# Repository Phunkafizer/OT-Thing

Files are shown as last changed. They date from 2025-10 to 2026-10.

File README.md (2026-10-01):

# OTthing

**A compact WiFi <-> OpenTherm (master & slave) interface**

## Project homepage

https://www.seegel-systeme.de/2025/01/05/ot-thing-das-universelle-wifi-opentherm-interface/

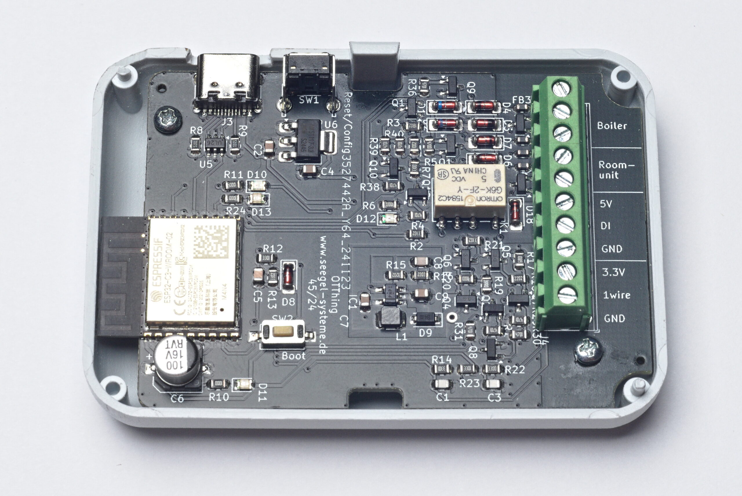
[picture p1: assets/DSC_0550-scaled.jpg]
OTthing OTthing board

*OTthing board*

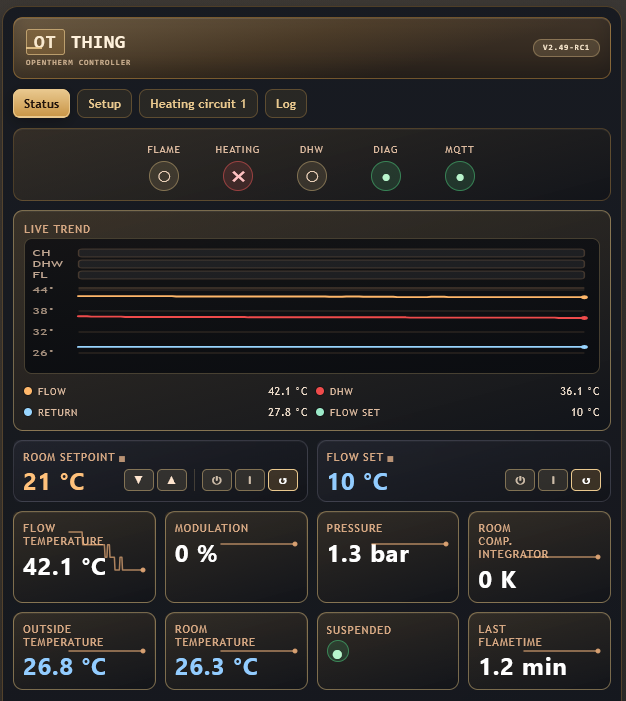
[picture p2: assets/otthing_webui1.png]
OTthing web UI OTthing web UI status

*OTthing web interface*

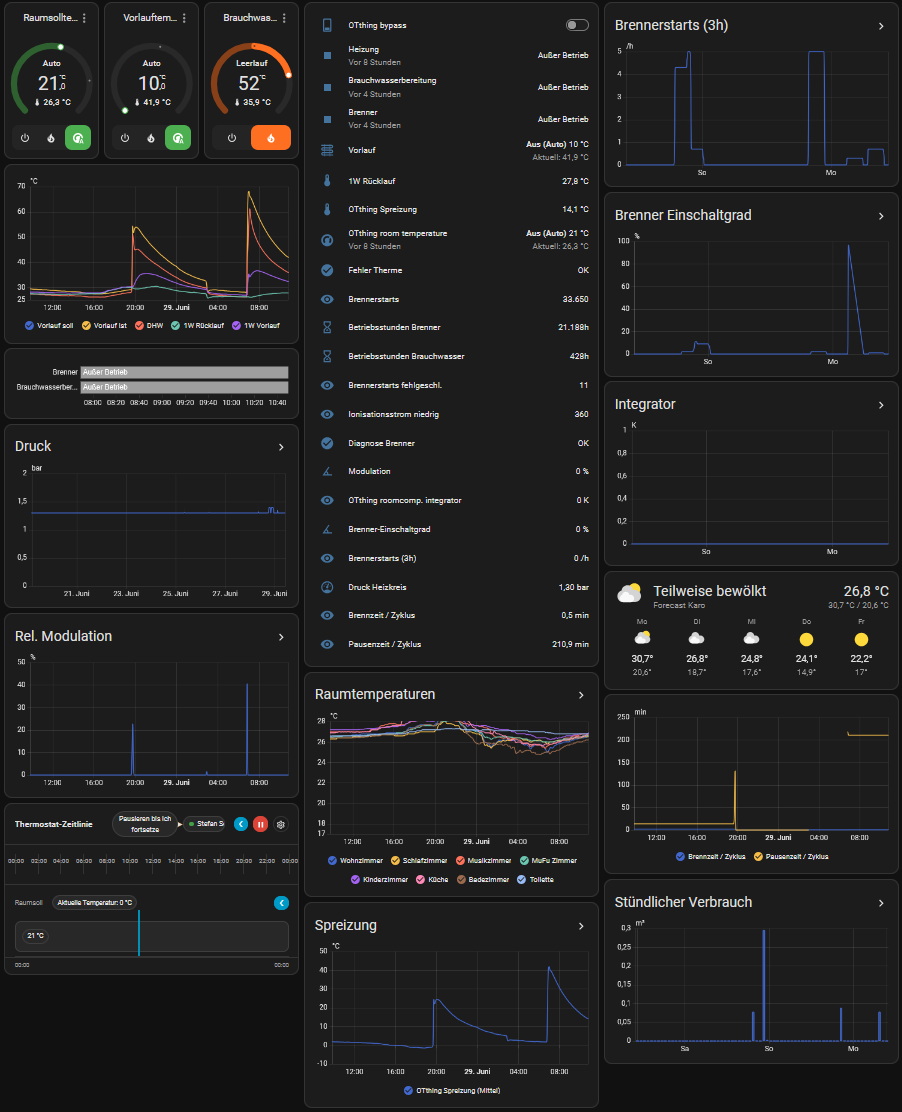
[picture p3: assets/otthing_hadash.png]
OTthing Home Assistant Dashboard OTthing Home Assistant dashboard

*Home Assistant integration*

## Overview

OTthing is a versatile OpenTherm gateway that connects your heating system to the Internet via WiFi. It acts as an OpenTherm master (controlling your boiler) and/or slave (integrating with room thermostats), providing real-time monitoring and control through a modern web interface and Home Assistant integration.

### Key Features

* **Dual OpenTherm Modes**: Operate as both an OpenTherm master and a slave simultaneously
* **Single-Board Compact Design**: Cost-efficient SMD-based single-board hardware with a small enclosure footprint
* **OpenTherm Compatibility**: Works with OpenTherm-compatible equipment that implements the functions supported by OTthing; available features vary by device
* **USB-C Powered**: Simple and reliable power supply through a standard USB-C connector
* **Web Dashboard**: Real-time status monitoring with system metrics
* **Home Assistant Integration**: Native MQTT discovery and seamless HA integration
* **Multi-Zone Support**: Control up to 2 heating circuits with independent parameters
* **Time Program**: Built-in scheduling for automatic heating setpoint changes
* **Heating Curve Control**: Outdoor-compensated flow temperature control with configurable curve parameters
* **Flow & Setpoint Management**: Fine-grained control for CH temperature targets, modes, and operating limits
* **Raw OpenTherm Tools**: Direct read/write request endpoint for diagnostics and advanced integrations
* **Real-Time Telemetry**: Live updates via WebSocket for logs and status changes
* **REST API**: Full HTTP interface for status, configuration, control commands, and topic discovery
* **WiFi Provisioning**: Built-in network scan and credential setup through the web interface
* **OTA Firmware Update**: In-browser firmware upload endpoint with automatic reboot on success
* **Local Data Export**: Device data and diagnostics export from the web UI for troubleshooting
* **External Inputs & Sensors**: Optional DS18B20, pulse input, or photointerrupter support (for example, condensate monitoring)
* **Selectable Operating Strategies**: Run OTthing as a full heating controller or in monitoring-first mode for telemetry-only operation
* **Automatic Bypass Behavior**: Allows you to restore conventional room-thermostat operation without rewiring
* **Failsafe Runtime Status**: Device health and communication state tracking for robust operation
* **Local Control**: Responsive web UI with no cloud dependency
* **Modular Design**: Extensible architecture supporting multiple integrations
* **Open-Source Platform**: Open hardware and firmware for custom extensions and modifications
* **Advanced Configuration**: Room modes (off/heat/auto), flow control, heating curves, and more
* **Detailed Logging**: Real-time log streaming to monitor system behavior
* **Turbo Mode**: Temporarily raises the flow target by a configurable amount and duration
* **Automatic Suspend**: Optional suspension based on outside temperature, room conditions, and minimum flow thresholds
* **Customizable dashboard**: add metrics to dashboard

## Architecture

The firmware consists of several functional modules:

* **OpenTherm Control** (`otcontrol.cpp`): Manages master/slave communication with the boiler
* **Master Requests** (`masterrequests.cpp`): Builds and schedules OpenTherm master requests and polling cycles
* **OpenTherm Values** (`otvalues.cpp`): Stores, normalizes, and exposes decoded OpenTherm data points
* **Heating Curve** (`heatingcurve.cpp`): Calculates the target flow temperature from heating-curve parameters
* **MQTT Integration** (`mqtt.cpp`): Publishes device state and subscribes to control topics
* **Device Status** (`devstatus.cpp`): Tracks runtime health, connectivity, and status flags
* **Auxiliary Input** (`auxInput.cpp`): Handles external input signals for additional control logic
* **Web Portal** (`portal.cpp`): Serves the responsive dashboard and API endpoints
* **Heating Control** (`CHcontrol.cpp`): Manages heating circuits, setpoints, and modes
* **Sensor Integration** (`sensors.cpp`): Collects data from external sensors
* **Configuration Management** (`devconfig.cpp`): Handles persistent device settings

## Hardware

* **MCU**: ESP32-C3 (or a compatible MCU with UART pins)
* **Communication**: OpenTherm interface
* **Power**: via USB
* **Optional**: DS18B20 1-Wire temperature sensors and auxiliary inputs

OpenTherm support and available controls depend on the boiler or other equipment. Check the device documentation and OTthing schematics before installation. Disconnect equipment from mains power before wiring; have boiler wiring performed by a qualified installer where required. Connect OpenTherm through the board's designated terminals, never directly to MCU GPIO pins.

## Installation & Setup

1. **Hardware Setup**:

   - Connect the OpenTherm slave side (boiler / ventilation / solar storage) to the **Boiler** screw terminal on OTthing
   - Optionally connect the room unit to the **Roomunit** screw terminals on OTthing
   - Connect OTthing to a USB-C power supply

2. **Access the Web Interface**:

   - The device creates a WiFi access point for provisioning or connects to its configured network
   - The default access point password is `12345678`; change it before deployment
   - Access the web UI at `http://<otthing-ip>/` (default: 4.3.2.1)

3. **Configure**:

   - Set your boiler type and heating circuit parameters
   - Configure the MQTT broker if you are using Home Assistant
   - Adjust setpoints, heating curves, and control modes

### Build and Flash (Developers)

Install PlatformIO, then run these commands from the `Firmware/` directory:

```bash
platformio run --environment release
platformio run --environment release --target upload
platformio run --environment release --target uploadfs
```

The first command builds the firmware. The next two upload the firmware and the LittleFS web assets; perform both uploads when installing a complete build. The firmware project reads access point SSID, password, and hostname from `default.ini` unless overridden by the build environment. Set a unique access point password before deploying devices.

## API Reference

OTthing exposes the following REST endpoints and WebSocket connection:

When web authentication is configured, protected endpoints require a valid login session. Requests without a valid session return 401; log in through the web UI before using these endpoints.

### Core Status Endpoints

* **`GET /`** - Web dashboard (HTML)
* **`GET /status`** - Current device and boiler status (JSON)
* **`GET /config`** - Device configuration and settings (JSON)
* **`POST /config`** - Update device configuration (JSON body)
* **`GET /otitems`** - Raw OpenTherm items and values from master and slave (JSON)
* **`GET /topics`** - List all available MQTT control topics (text/plain)

### Control Endpoints

* **`GET /set?key=value`** - Update settings via query parameters
  - Examples: `/set?chSetTemp1=50`, `/set?chMode1=heat`
  - Use `/topics` to discover supported control keys. URL-encode values when they contain reserved characters.
  - Returns 200 on success, 503 if the value cannot be set

* **`GET /slaverequest?id=X&rw=Y&data=HEX`** - Send a raw OpenTherm slave request
  - `id`: OpenTherm message ID (integer)
  - `rw`: 1 for READ_DATA, 0 for WRITE_DATA
  - `data`: Hex-encoded data value
  - Returns JSON with response type, ID, and data

### System Endpoints

* **`GET /scan`** - Scan for available WiFi networks
  - Returns JSON with the SSID, RSSI, and channel for each network
  - Status field: -2 (scanning in progress), -1 (failed), 0+ (number of networks found)

* **`POST /setwifi`** - Configure WiFi credentials
  - Parameters: `ssid` and `pass` (URL-encoded)
  - Triggers a device reboot and a WiFi connection attempt

* **`GET /reboot`** - Trigger a device reboot
  - Returns 200 and schedules a reboot

* **`POST /update`** - Firmware update (binary upload)
  - Returns 200 on success, 500/503 on error
  - Triggers an automatic reboot if the update succeeds

### Real-time Communication

* **`WebSocket /ws`** - Real-time updates and log streaming
  - Receives log messages and status updates
  - Can be used to monitor device behavior in real time

## Testing & Development

A Python mock server is included for local UI and API testing. Install its dependencies and start it from the `Firmware/` directory:

```bash
python -m pip install -r requirements.txt
python tools/mock_otthing.py
```

The server listens on `http://127.0.0.1:8081/`. It is useful for UI development and API integration, but it does not replace testing against physical OpenTherm hardware.

### MQTT Notes

The device subscribes to control topics under `otthing/<device-id>/<key>/set`; `/topics` lists the supported keys. Home Assistant discovery is provided through MQTT when a broker is configured.

Changes sent through the web API are also published to the corresponding MQTT `/set` topic as retained messages. A broker can replay retained commands when the device reconnects, including after a reboot. Keep this in mind for temporary controls such as Turbo mode, and clear any stale retained command from the broker when needed.

### Troubleshooting

* **Cannot reach the web UI**: Confirm the phone or computer is connected to the OTthing access point or the same network as the device, then check the device IP.
* **No OpenTherm communication**: Check the board terminals, wiring polarity where applicable, boiler compatibility, and the device's status and logs.
* **Home Assistant entities are missing**: Confirm broker connectivity and MQTT discovery settings, then review device logs and the broker's topics.
* **A setting returns 401**: Log in through the web UI and retry the request with the browser session.
* **A temporary action returns after reboot**: Check whether a retained MQTT `/set` command is replaying it.

## Schematics

OTthing schematic 1 OTthing schematic page 1
OTthing schematic 2 OTthing schematic page 2

## Discussion

https://community.home-assistant.io/t/ot-thing-an-opentherm-wifi-gateway-with-integrated-ot-master-slave/824667

## Reporting issues

When reporting issues, please supply:

* Brand and model of the boiler and room unit
* OTthing firmware version and the steps that reproduce the issue
* Log
* Status JSON
* Configuration JSON
* OT items JSON
* Data history JSON

All of this data can be exported from OTthing using the export function at the bottom of the web UI.

## Contributing

* Make changes in a new branch based on the [`develop`](../../tree/develop) branch.
* Address only one issue per PR.
* Create the PR against the [`develop`](../../tree/develop) branch.

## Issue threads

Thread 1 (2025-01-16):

Log is not supported

kuqqum, 2025-01-16:
In the userinterfase there is a menu tab "log". In this tab there is no functionality at all. Can you provide this service. It wil help tracing down existing issues.

Regards.
Joop

kuqqum, 2025-01-16:
I do have a blinking led D10. I don't now Why.

Phunkafizer, 2025-01-16:
logpage works in v1.4
D10 flahes when a frame is received from boiler (OT master interface)

kuqqum, 2025-01-16:
Hallo,Der Thermostat ist noch blockiert. Met vriendelijke groet,Joop HilverinkOp 16 jan 2025 om 21:01 heeft Stefan S ***@***.***> het volgende geschreven:
logpage works in v1.4
D10 flahes when a frame is received from boiler (OT master interface)

—Reply to this email directly, view it on GitHub, or unsubscribe.You are receiving this because you authored the thread.Message ID: ***@***.***>

kuqqum, 2025-01-16:
Hallo,Obwohl „Gateway“ ist actief OT Thing funktioniert nur als „Master“. Brauchwassern funktioniert noch nicht. Außentemperatur zeigt 0. Einstellung ist „mqtt“. Met vriendelijke groet,Joop HilverinkOp 16 jan 2025 om 22:15 heeft Joop Hilverink ***@***.***> het volgende geschreven: Hallo,Der Thermostat ist noch blockiert. <image0.png><image1.png>Met vriendelijke groet,Joop HilverinkOp 16 jan 2025 om 21:01 heeft Stefan S ***@***.***> het volgende geschreven:
logpage works in v1.4
D10 flahes when a frame is received from boiler (OT master interface)

—Reply to this email directly, view it on GitHub, or unsubscribe.You are receiving this because you authored the thread.Message ID: ***@***.***>

Phunkafizer, 2025-01-16:
Hallo!

Können Sie mir

  *
die Ausgabe von der LOG Seite
  *
die Ausgabe von http://<IP OT Thing>/status
  *
die Ausgabe von http://<IP OT Thing>/config

senden?

Blinkt die LED D13 (Empfang OT Thermostat) ebenfalls?
Wieviel Strom kann Ihr USB-C Netzgerät liefern?

Die Außentemperatur wird im Gatewaymode nicht verwendet, daher wird 0 angezeigt.
________________________________
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

kuqqum, 2025-01-17:
Hallo Stefan,
Für das Einschalten von OTThing habe ich lange gewartet, um sicherzustellen, dass die OT-Verbindung fehlerfrei ist und das Thermostat über die drei Bedienelemente steuerbar ist. Die Taste in der Mitte blinkt nicht (Fehleranzeige).
Nach dem Einschalten/Starten von OTThing funktioniert alles für kurze Zeit einwandfrei. Das Thermostat ist über die drei Tasten steuerbar, und die mittlere Taste blinkt nicht.
Nach einiger Zeit beginnt die Taste blau zu blinken, und das Thermostat "friert ein".
Die LED D13 blinkt grün und die LED D10 blinkt rot.
Das USB-C-Gerät liefert 2,1 A.

Joop

________________________________
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

Phunkafizer, 2025-01-17:
Hallo Joop,

die Kommunikation sieht fehlerfrei aus! Am besten mal den Hersteller fragen was es bedeutet wenn es einfriert und blinkt. Mit meinem Thermostat Hoval RS-OT klappt es prima.

Schöne Grüße
Stefan
________________________________
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

kuqqum, 2025-01-17:
Hallo Stefan,
Blaues Blinken bedeutet, dass eine (Fehler-)Meldung vorliegt. Im normalen Betrieb, ohne OTThing, kann ich die Meldung mit dieser Taste auslesen. Mit aktiviertem OTThing ist dies jedoch aufgrund der blockierten Bedienung nicht möglich.
Viele Grüße,
Joop

________________________________
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

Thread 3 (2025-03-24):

Device unavailable after reset

mirino75, 2025-03-24:
Hello,

I have the device connected as a gateway because I want to use it simultaneously with the old thermostat.
I have the device configured and it receives data, but after pressing "Save" and "Reboot" (or if I disconnect it from the usb-c adapter) the device disconnects and is no longer available on the network. Not even PING. In the picture, PING starts, but when I press the button again for 2 seconds and I get into config mode.

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

Miro

mirino75, 2025-03-24:
I updated the firmware to 1.7, after pressing SAVE the device is inaccessible
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

Phunkafizer, 2025-04-04:
please try with the latest webflasher:

otthing.seegel-systeme.de

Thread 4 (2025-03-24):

MQTT: Bad socket read/write on client <unknown>: Malformed UTF-8

mirino75, 2025-03-24:
Hello,
I have a error in mqtt.log:
Bad socket read/write on client <unknown>: Malformed UTF-8

1. Device connected to mqtt broker time 09:10-09:12
2. Device **disconnected** to mqtt broker time 09:12-09:16
3. Device connected to mqtt broker time 09:16

I also see in mqtt explorer that only topic _otthing/31F434/state_ is updated... The other topics are updated only once, after the device is restarted.

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

Phunkafizer, 2025-03-25:
Thanks for your report, I'm working on a new firmware version.

Phunkafizer, 2025-04-01:
Version v2.0 is available. Please note that update from v1.x to v2.x is only possible via USB Cable, not via web interface. To programm via USB the webflasher can be used:
https://otthing.seegel-systeme.de/

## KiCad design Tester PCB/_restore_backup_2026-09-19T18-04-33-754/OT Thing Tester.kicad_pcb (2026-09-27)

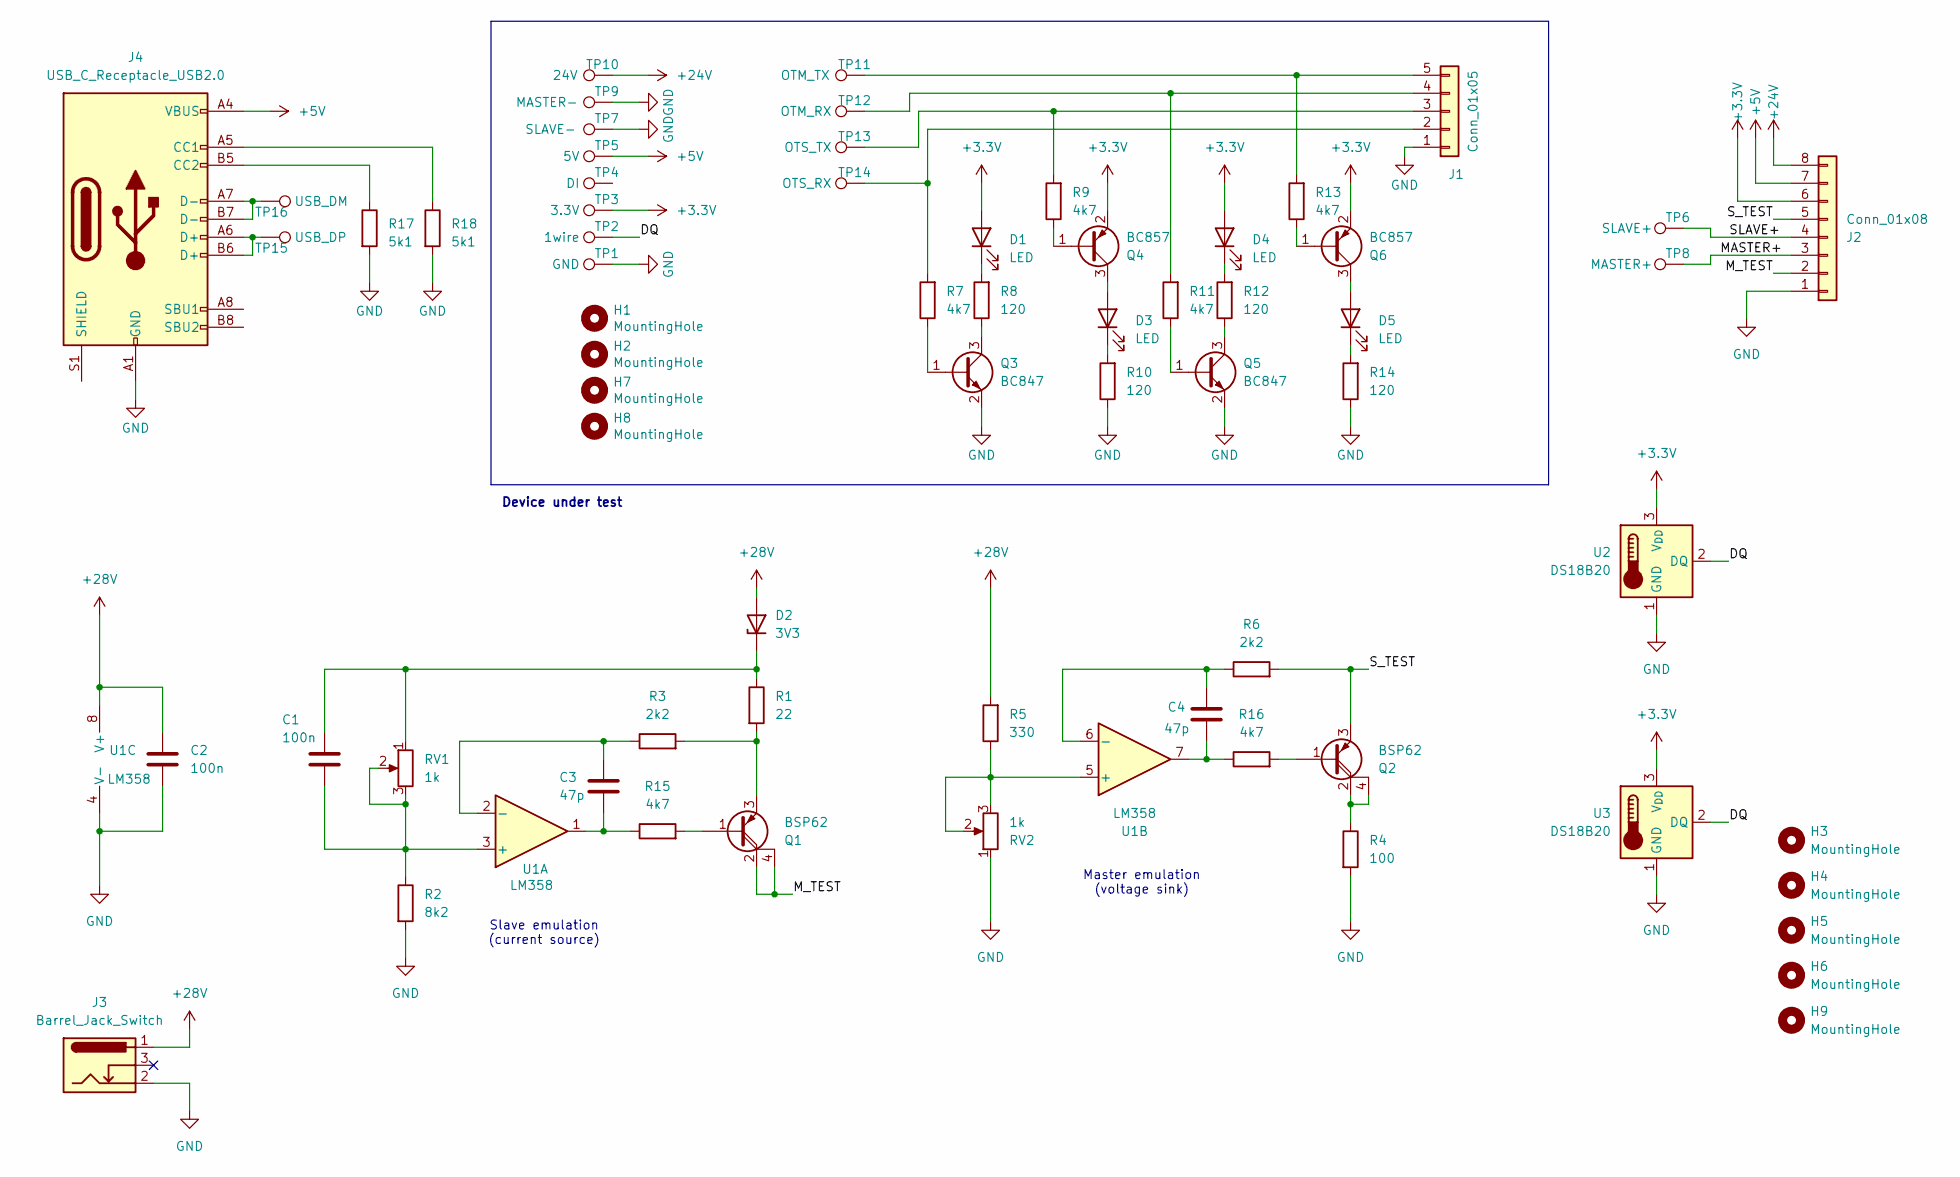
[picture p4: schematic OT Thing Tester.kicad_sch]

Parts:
C1, C2: 100n; C_0805_2012Metric
C3, C4: 47p; C_0805_2012Metric
D1, D3, D4, D5: LED; LED_0805_2012Metric
D2: 3V3; D_MiniMELF
H1, H2, H7, H8: MountingHole; MountingHole_2.7mm_M2.5
H3, H4, H5, H6, H9: MountingHole; MountingHole_3.2mm_M3_DIN965_Pad
J1: Conn_01x05; PinHeader_1x05_P2.54mm_Vertical
J2: Conn_01x08; PinHeader_1x08_P2.54mm_Vertical
J3: Barrel_Jack_Switch; BarrelJack_GCT_DCJ200-10-A_Horizontal
J4: USB_C_Receptacle_USB2.0; USB_C_Receptacle_HRO_TYPE-C-31-M-12; LCSC C2927038
Q1, Q2: BSP62; SOT-223
Q3, Q5: BC847; SOT-23
Q4, Q6: BC857; SOT-23
R1: 22; R_0805_2012Metric
R2: 8k2; R_0805_2012Metric
R3, R6: 2k2; R_0805_2012Metric
R4: 100; R_0805_2012Metric
R5: 330; R_0805_2012Metric
R7, R9, R11, R13, R15, R16: 4k7; R_0805_2012Metric
R8, R10, R12, R14: 120; R_0805_2012Metric
R17, R18: 5k1; R_0805_2012Metric; LCSC C118848
RV1, RV2: 1k; Potentiometer_Bourns_3266Y_Vertical
TP1: GND; TestPoint_THTPad_D2.0mm_Drill1.1mm
TP2: 1wire; TestPoint_THTPad_D2.0mm_Drill1.1mm
TP3: 3.3V; TestPoint_THTPad_D2.0mm_Drill1.1mm
TP4: DI; TestPoint_THTPad_D2.0mm_Drill1.1mm
TP5: 5V; TestPoint_THTPad_D2.0mm_Drill1.1mm
TP6: SLAVE+; TestPoint_THTPad_D2.0mm_Drill1.1mm
TP7: SLAVE-; TestPoint_THTPad_D2.0mm_Drill1.1mm
TP8: MASTER+; TestPoint_THTPad_D2.0mm_Drill1.1mm
TP9: MASTER-; TestPoint_THTPad_D2.0mm_Drill1.1mm
TP10: 24V; TestPoint_THTPad_D2.0mm_Drill1.1mm
TP11: OTM_TX; TestPoint_THTPad_D2.0mm_Drill1.1mm
TP12: OTM_RX; TestPoint_THTPad_D2.0mm_Drill1.1mm
TP13: OTS_TX; TestPoint_THTPad_D2.0mm_Drill1.1mm
TP14: OTS_RX; TestPoint_THTPad_D2.0mm_Drill1.1mm
TP15: USB_DP; TestPoint_THTPad_D2.0mm_Drill1.1mm
TP16: USB_DM; TestPoint_THTPad_D2.0mm_Drill1.1mm
U1: LM358; SO-8_3.9x4.9mm_P1.27mm
U2, U3: DS18B20; TO-92_Inline

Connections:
+3.3V: D1.2 (A), D4.2 (A), J2.6, Q4.2 (E), Q6.2 (E), TP3.1 (1_1), U2.3 (V_{DD}), U3.3 (V_{DD})
+5V: J2.7, J4.A4 (VBUS), J4.A9 (VBUS), J4.B4 (VBUS), J4.B9 (VBUS), TP5.1 (1_1)
+24V: J2.8, TP10.1 (1_1)
+28V: C2.1, D2.2 (A), J3.1, R5.2, U1.8 (V+)
/DQ: TP2.1 (1_1), U2.2 (DQ), U3.2 (DQ)
/MASTER+: J2.3, TP8.1 (1_1)
/M_TEST: J2.2, Q1.2 (C), Q1.4 (C)
/SLAVE+: J2.4, TP6.1 (1_1)
/S_TEST: J2.5, Q2.3 (E), R6.2
GND: C2.2, J1.1, J2.1, J3.2, J4.A1 (GND), J4.A12 (GND), J4.B1 (GND), J4.B12 (GND), Q3.2 (E), Q5.2 (E), R2.2, R4.2, R10.1, R14.1, R17.2, R18.2, RV2.1, TP1.1 (1_1), TP7.1 (1_1), TP9.1 (1_1), U1.4 (V-), U2.1 (GND), U3.1 (GND)
unnamed: C3.2, R15.1, U1.1
unnamed: C4.2, R16.1, U1.7
unnamed: D1.1 (K), R8.2
unnamed: C1.2, D2.1 (K), R1.1, RV1.1
unnamed: D3.2 (A), Q4.3 (C)
unnamed: D3.1 (K), R10.2
unnamed: D4.1 (K), R12.2
unnamed: D5.2 (A), Q6.3 (C)
unnamed: D5.1 (K), R14.2
unnamed: J1.2, R7.2, TP14.1 (1_1)
unnamed: J1.3, R9.2, TP13.1 (1_1)
unnamed: J1.4, R11.2, TP12.1 (1_1)
unnamed: J1.5, R13.2, TP11.1 (1_1)
unnamed: J4.A5 (CC1), R18.1
unnamed: J4.B5 (CC2), R17.1
unnamed: J4.A6 (D+), J4.B6 (D+), TP15.1 (1_1)
unnamed: J4.A7 (D-), J4.B7 (D-), TP16.1 (1_1)
unnamed: Q1.1 (B), R15.2
unnamed: Q1.3 (E), R1.2, R3.2
unnamed: Q2.1 (B), R16.2
unnamed: Q2.2 (C), Q2.4 (C), R4.1
unnamed: Q3.1 (B), R7.1
unnamed: Q3.3 (C), R8.1
unnamed: Q4.1 (B), R9.1
unnamed: Q5.1 (B), R11.1
unnamed: Q5.3 (C), R12.1
unnamed: Q6.1 (B), R13.1
unnamed: C1.1, R2.1, RV1.2, RV1.3, U1.3 (+)
unnamed: C3.1, R3.1, U1.2 (-)
unnamed: R5.1, RV2.2, RV2.3, U1.5 (+)
unnamed: C4.1, R6.1, U1.6 (-)

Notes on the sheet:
Master emulation (voltage sink)
Slave emulation (current source)
Device under test

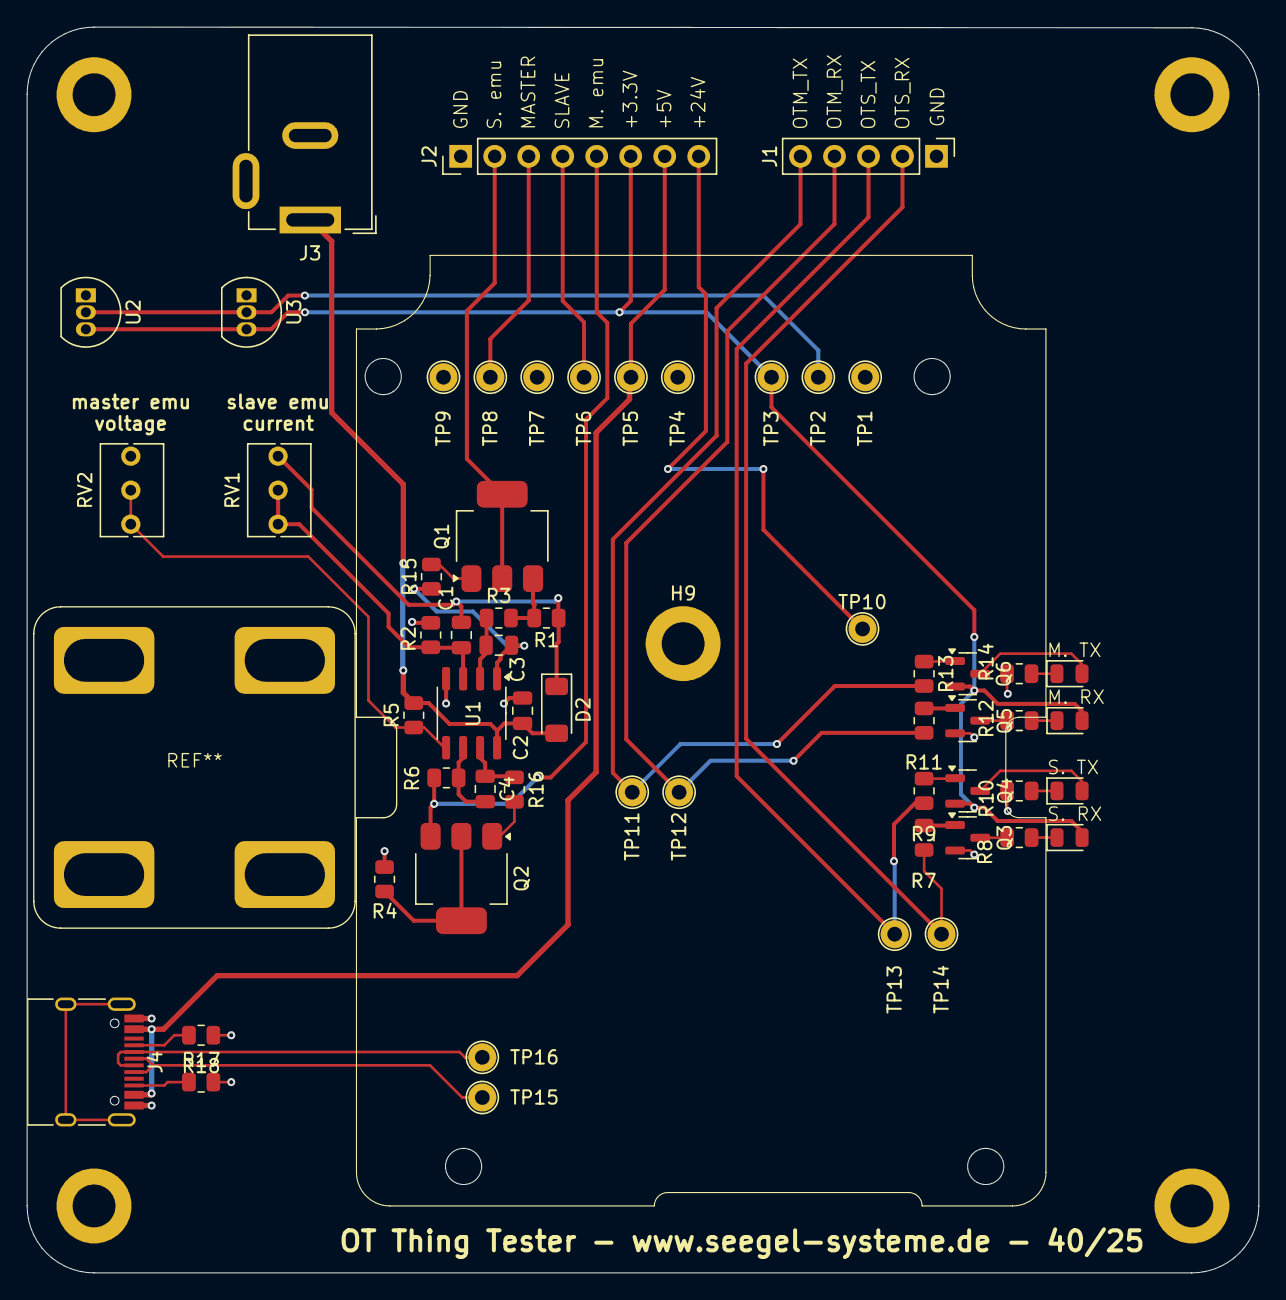
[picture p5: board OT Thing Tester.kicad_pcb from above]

Board: 2 copper layers, 92.0 x 93.0 mm, 67 parts (0 on the bottom side), 41 nets.

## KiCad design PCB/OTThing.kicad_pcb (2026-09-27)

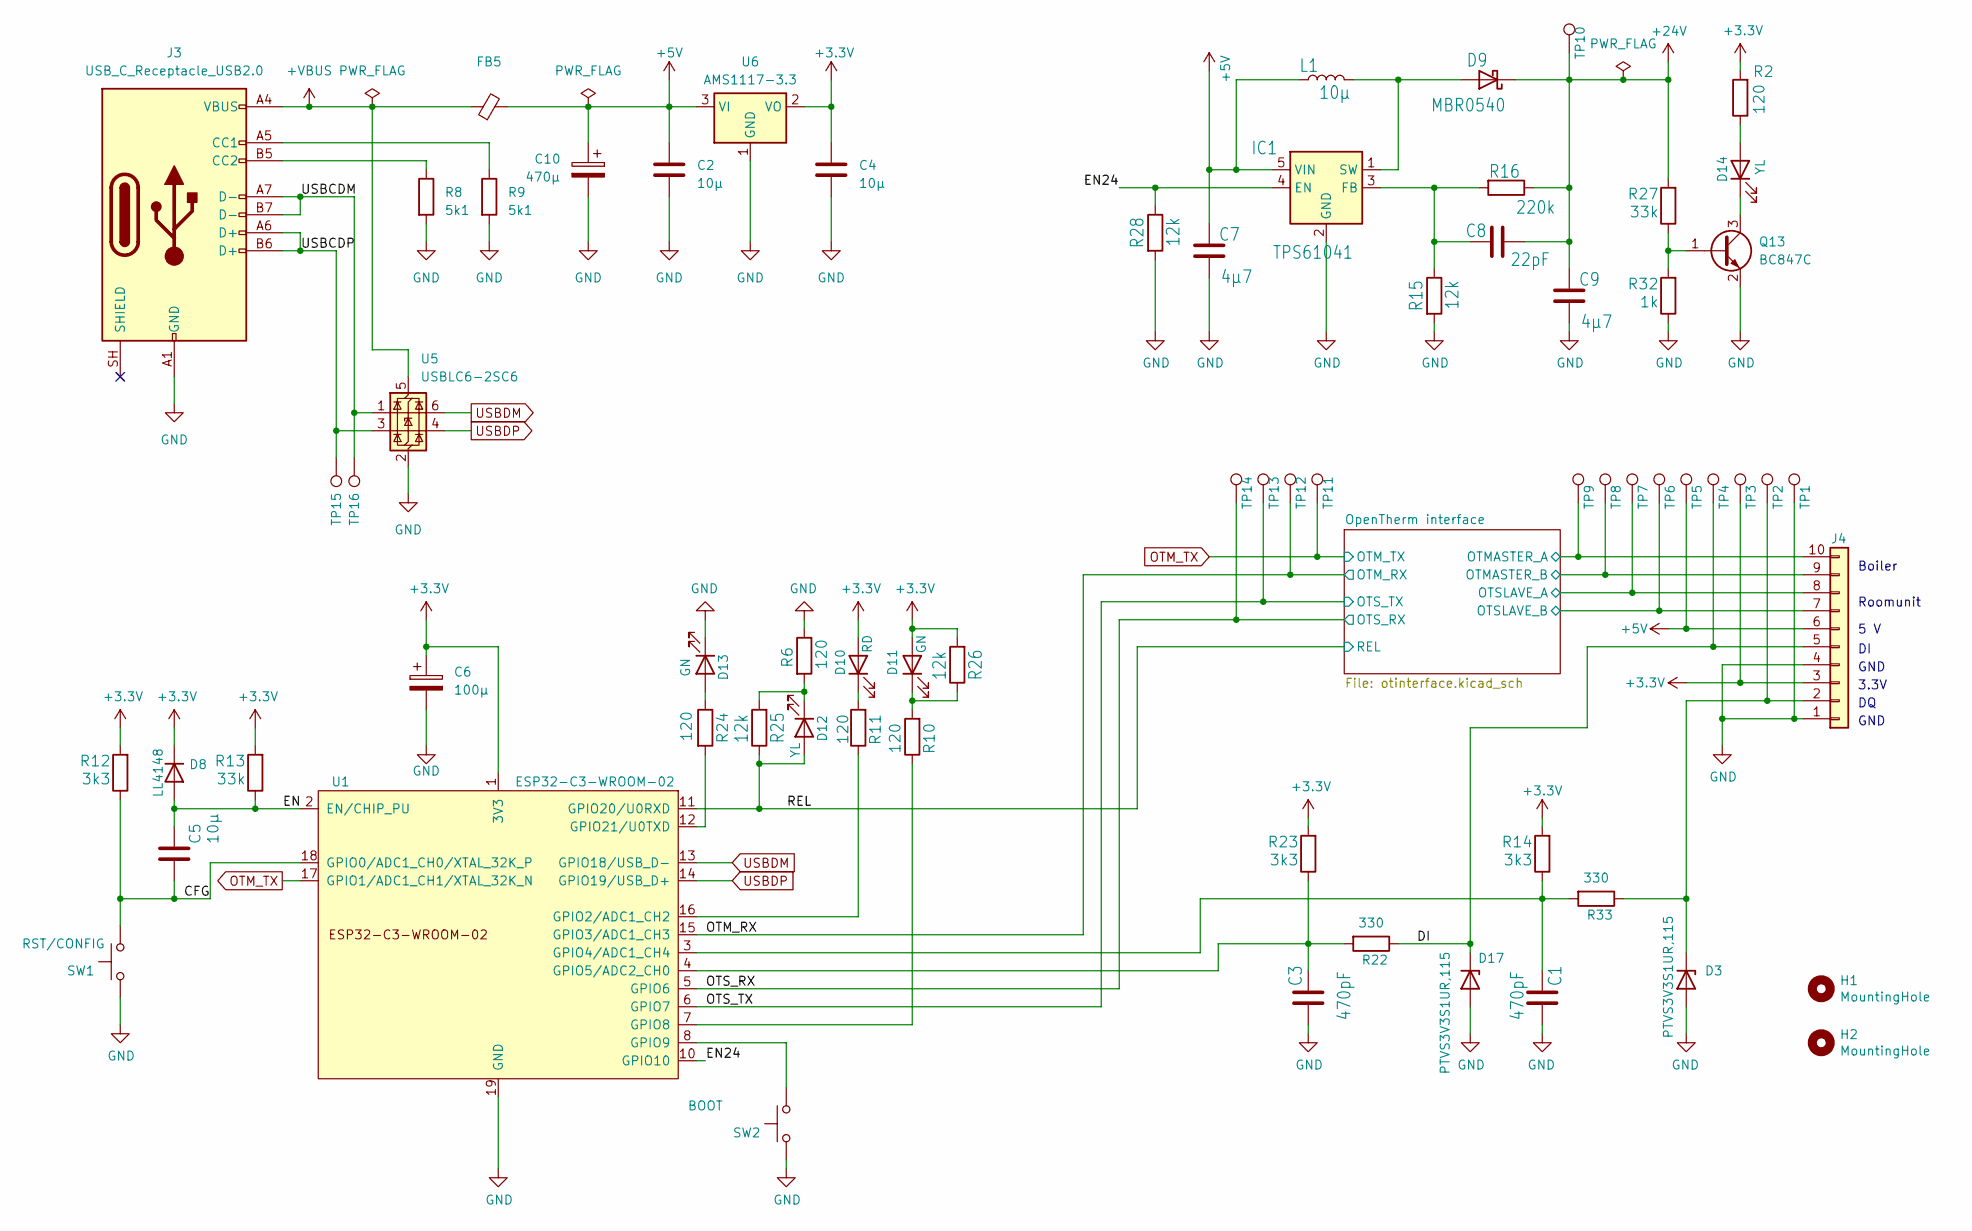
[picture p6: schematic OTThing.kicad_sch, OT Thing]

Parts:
C1, C3: 470pF; C_0805_2012Metric; LCSC C62771
C2, C4, C5: 10µ; C_0805_2012Metric; LCSC C90543
C6: 100µ; CP_Elec_6.3x5.4; LCSC C2887276
C7, C9: 4µ7; C_0805_2012Metric; LCSC C2918489
C8: 22pF; C_0805_2012Metric; LCSC C24658
C10: 470µ; CP_Elec_6.3x7.7; LCSC C87858
D3, D17: PTVS3V3S1UR,115; D_SOD-123; LCSC C183521
D8: LL4148; D_MiniMELF; LCSC C435829
D9: MBR0540; D_SOD-123; LCSC C116159
D10: RD; LED_0805_2012Metric; LCSC C2943978
D11, D13: GN; LED_0805_2012Metric; LCSC C965815
D12, D14: YL; LED_0805_2012Metric; LCSC C965816
FB5: L_0603_1608Metric; LCSC C1002
H1, H2: MountingHole; MountingHole_2.5mm
IC1: TPS61041; SOT-23-5; LCSC C9846
J3: USB_C_Receptacle_USB2.0; USB_C_Receptacle_HRO_TYPE-C-31-M-12; LCSC C2927038
J4: TerminalBlock_Phoenix_PT-1,5-10-3.5-H_1x10_P3.50mm_Horizont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; LCSC C5184956
L1: 10µ; L_1210_3225Metric; LCSC C98020
Q13: BC847C; SOT-23; LCSC C7420337
R2, R6, R10, R11, R24: 120; R_0805_2012Metric; LCSC C17437
R8, R9: 5k1; R_0805_2012Metric; LCSC C118848
R12, R14, R23: 3k3; R_0805_2012Metric; LCSC C26010
R13, R27: 33k; R_0805_2012Metric; LCSC C17633
R15, R25, R26, R28: 12k; R_0805_2012Metric; LCSC C17444
R16: 220k; R_0805_2012Metric; LCSC C17556
R22, R33: 330; R_0805_2012Metric; LCSC C17630
R32: 1k; R_0805_2012Metric; LCSC C17513
SW1: RST/CONFIG; SW_Tactile_SPST_Angled_PTS645Vx83-2LFS; LCSC C2837540
SW2: BOOT; SW_SPST_CK_RS282G05A3; LCSC C2888954
TP1, TP2, TP3, TP4, TP5, TP6, TP7, TP8, TP9, TP10, TP11, TP12, TP13, TP14, TP15, TP16: TestPoint_THTPad_D1.5mm_Drill0.7mm
U1: ESP32-C3-WROOM-02; LCSC C2934560
U5: USBLC6-2SC6; SOT-23-6; LCSC C2827654
U6: AMS1117-3.3; SOT-223-3_TabPin2; LCSC C347222

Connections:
+3.3V: C4.1, C6.1, D8.1 (K), D10.2 (A), D11.2 (A), J4.3, R2.2, R12.2, R13.2, R14.2, R23.2, R26.2, TP3.1 (1_1), U1.1 (3V3), U6.2 (VO); also elsewhere on the board
+5V: C2.1, C7.1, C10.1, FB5.2, IC1.5 (VIN), J4.6, L1.1, TP5.1 (1_1), U6.3 (VI); also elsewhere on the board
+24V: C8.1, C9.1, D9.1 (K), R16.1, R27.2, TP10.1 (1_1); also elsewhere on the board
+VBUS: FB5.1, J3.A4 (VBUS), J3.A9 (VBUS), J3.B4 (VBUS), J3.B9 (VBUS), U5.5 (VBUS)
/CFG: C5.2, R12.1, SW1.1, U1.18 (GPIO0/ADC1_CH0/XTAL_32K_P)
/DI: D17.1 (K), J4.5, R22.1, TP4.1 (1_1)
/EN: C5.1, D8.2 (A), R13.1, U1.2 (EN/CHIP_PU)
/EN24: IC1.4 (EN), R28.1, U1.10 (GPIO10)
/OTM_RX: TP12.1 (1_1), U1.15 (GPIO3/ADC1_CH3); also elsewhere on the board
/OTS_RX: TP14.1 (1_1), U1.5 (GPIO6); also elsewhere on the board
/OTS_TX: TP13.1 (1_1), U1.6 (GPIO7); also elsewhere on the board
/OpenTherm interface/OTMASTER_A: J4.10, TP9.1 (1_1); also elsewhere on the board
/OpenTherm interface/OTMASTER_B: J4.9, TP8.1 (1_1); also elsewhere on the board
/OpenTherm interface/OTSLAVE_A: J4.8, TP7.1 (1_1); also elsewhere on the board
/OpenTherm interface/OTSLAVE_B: J4.7, TP6.1 (1_1); also elsewhere on the board
/REL: D12.2 (A), R25.1, U1.11 (GPIO20/U0RXD); also elsewhere on the board
/USBCDM: J3.A7 (D-), J3.B7 (D-), TP16.1 (1_1), U5.1 (I/O1)
/USBCDP: J3.A6 (D+), J3.B6 (D+), TP15.1 (1_1), U5.3 (I/O2)
GND: C1.2, C2.2, C3.2, C4.2, C6.2, C7.2, C9.2, C10.2, D3.2 (A), D13.1 (K), D17.2 (A), IC1.2 (GND), J3.A1 (GND), J3.A12 (GND), J3.B1 (GND), J3.B12 (GND), J4.1, J4.4, Q13.2 (E), R6.1, R8.2, R9.2, R15.2, R28.2, R32.1, SW1.2, SW2.2, TP1.1 (1_1), U1.9 (GND), U1.19 (GND), U5.2 (GND), U6.1 (GND); also elsewhere on the board
unnamed: D3.1 (K), J4.2, R33.1, TP2.1 (1_1)
unnamed: D9.2 (A), IC1.1 (SW), L1.2
unnamed: D10.1 (K), R11.2
unnamed: D11.1 (K), R10.2, R26.1
unnamed: D12.1 (K), R6.2, R25.2
unnamed: D13.2 (A), R24.1
unnamed: D14.2 (A), R2.1
unnamed: D14.1 (K), Q13.3 (C)
unnamed: C8.2, IC1.3 (FB), R15.1, R16.2
unnamed: J3.A5 (CC1), R9.1
unnamed: J3.B5 (CC2), R8.1
unnamed: Q13.1 (B), R27.1, R32.2
unnamed: R11.1, U1.16 (GPIO2/ADC1_CH2)
unnamed: C1.1, R14.1, R33.2, U1.3 (GPIO4/ADC1_CH4)
unnamed: C3.1, R22.2, R23.1, U1.4 (GPIO5/ADC2_CH0)
unnamed: R10.1, U1.7 (GPIO8)
unnamed: SW2.1, U1.8 (GPIO9)
unnamed: R24.2, U1.12 (GPIO21/U0TXD)
OTM_TX: TP11.1 (1_1), U1.17 (GPIO1/ADC1_CH1/XTAL_32K_N); also elsewhere on the board
USBDM: U1.13 (GPIO18/USB_D-), U5.6 (I/O1)
USBDP: U1.14 (GPIO19/USB_D+), U5.4 (I/O2)

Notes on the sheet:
Boiler
3.3V
GND
5 V
Roomunit

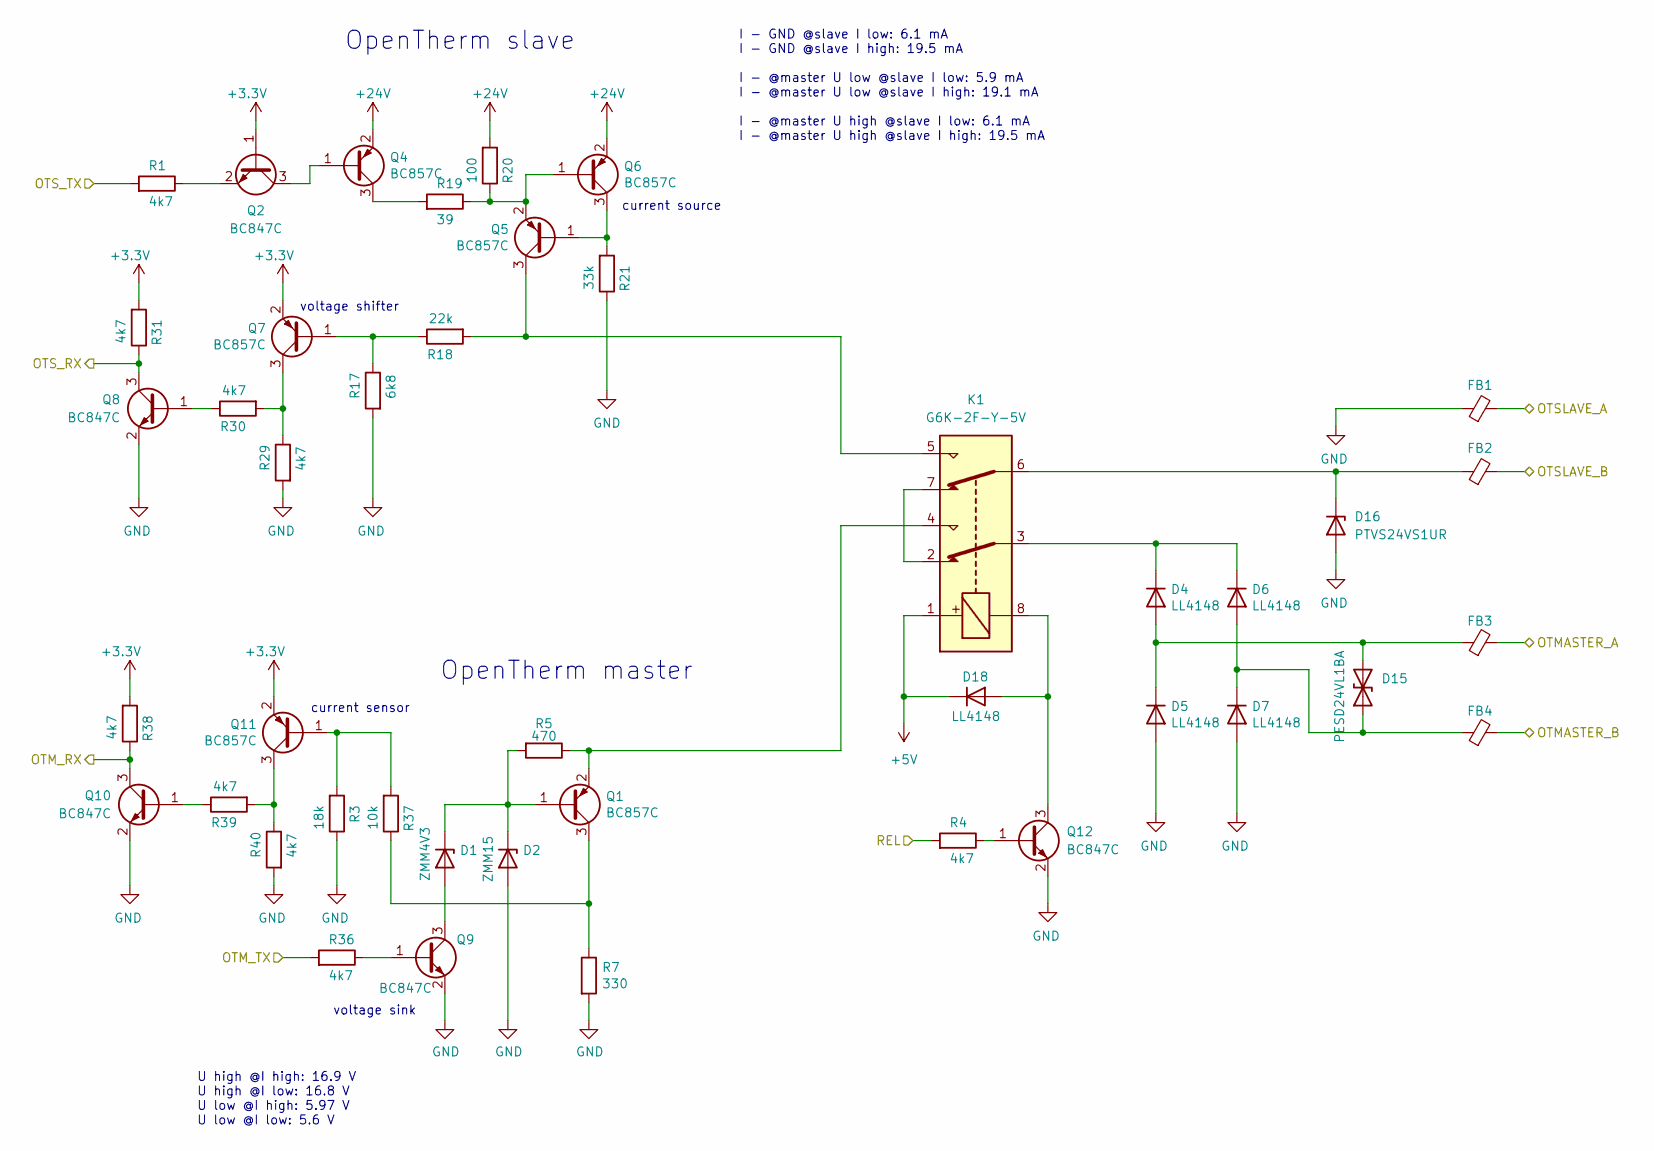
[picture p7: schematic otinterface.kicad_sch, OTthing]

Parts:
D1: ZMM4V3; D_MiniMELF; LCSC C5345990
D2: ZMM15; D_MiniMELF; LCSC C5346000
D4, D5, D6, D7, D18: LL4148; D_MiniMELF; LCSC C435829
D15: PESD24VL1BA; D_SOD-323; LCSC C2687132
D16: PTVS24VS1UR; D_SOD-123; LCSC C5380693
FB1, FB2, FB3, FB4: L_0603_1608Metric; LCSC C1002
K1: G6K-2F-Y-5V; Relay_DPDT_Omron_G6K-2F-Y; LCSC C2982926
Q1, Q4, Q5, Q6, Q7, Q11: BC857C; SOT-23; LCSC C5204725
Q2, Q8, Q9, Q10, Q12: BC847C; SOT-23; LCSC C7420337
R1, R4, R29, R30, R31, R36, R38, R39, R40: 4k7; R_0805_2012Metric; LCSC C17673
R3: 18k; R_0805_2012Metric; LCSC C17506
R5: 470; R_0805_2012Metric; LCSC C17710
R7: 330; R_0805_2012Metric; LCSC C17630
R17: 6k8; R_0805_2012Metric; LCSC C17772
R18: 22k; R_0805_2012Metric; LCSC C17560
R19: 39; R_0805_2012Metric; LCSC C137534
R20: 100; R_0805_2012Metric; LCSC C17408
R21: 33k; R_0805_2012Metric; LCSC C17633
R37: 10k; R_0805_2012Metric; LCSC C17414

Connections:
+3.3V: Q2.1 (B), Q7.2 (E), Q11.2 (E), R31.2, R38.2; also elsewhere on the board
+5V: D18.1 (K), K1.1; also elsewhere on the board
+24V: Q4.2 (E), Q6.2 (E), R20.2; also elsewhere on the board
/OTM_RX: Q10.3 (C), R38.1; also elsewhere on the board
/OTS_RX: Q8.3 (C), R31.1; also elsewhere on the board
/OTS_TX: R1.2; also elsewhere on the board
/OpenTherm interface/OTMASTER_A: FB3.2; also elsewhere on the board
/OpenTherm interface/OTMASTER_B: FB4.2; also elsewhere on the board
/OpenTherm interface/OTSLAVE_A: FB1.2; also elsewhere on the board
/OpenTherm interface/OTSLAVE_B: FB2.2; also elsewhere on the board
/REL: R4.2; also elsewhere on the board
GND: D2.2 (A), D5.2 (A), D7.2 (A), D16.2 (A), FB1.1, Q8.2 (E), Q9.2 (E), Q10.2 (E), Q12.2 (E), R3.1, R7.2, R17.2, R21.1, R29.2, R40.2; also elsewhere on the board
unnamed: D1.2 (A), Q9.3 (C)
unnamed: D1.1 (K), D2.1 (K), Q1.1 (B), R5.2
unnamed: D4.1 (K), D6.1 (K), K1.3
unnamed: D6.2 (A), D7.1 (K), D15.1 (A1), FB4.1
unnamed: D4.2 (A), D5.1 (K), D15.2 (A2), FB3.1
unnamed: D16.1 (K), FB2.1, K1.6
unnamed: D18.2 (A), K1.8, Q12.3 (C)
unnamed: K1.2, K1.7
unnamed: Q1.3 (C), R7.1, R37.1
unnamed: K1.4, Q1.2 (E), R5.1
unnamed: Q2.3 (C), Q4.1 (B)
unnamed: Q2.2 (E), R1.1
unnamed: Q4.3 (C), R19.2
unnamed: Q5.1 (B), Q6.3 (C), R21.2
unnamed: K1.5, Q5.3 (C), R18.2
unnamed: Q5.2 (E), Q6.1 (B), R19.1, R20.1
unnamed: Q7.1 (B), R17.1, R18.1
unnamed: Q7.3 (C), R29.1, R30.2
unnamed: Q8.1 (B), R30.1
unnamed: Q9.1 (B), R36.1
unnamed: Q10.1 (B), R39.1
unnamed: Q11.1 (B), R3.2, R37.2
unnamed: Q11.3 (C), R39.2, R40.1
unnamed: Q12.1 (B), R4.1
OTM_TX: R36.2; also elsewhere on the board

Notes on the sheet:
current sensor
current source
U high @I high: 16.9 V U high @I low: 16.8 V U low @I high: 5.97 V U low @I low: 5.6 V
I - GND @slave I low: 6.1 mA I - GND @slave I high: 19.5 mA I - @master U low @slave I low: 5.9 mA I - @master U low @slave I high: 19.1 mA I - @master U high @slave I low: 6.1 mA I - @master U high @slave I high: 19.5 mA
voltage shifter
OpenTherm slave
OpenTherm master
voltage sink

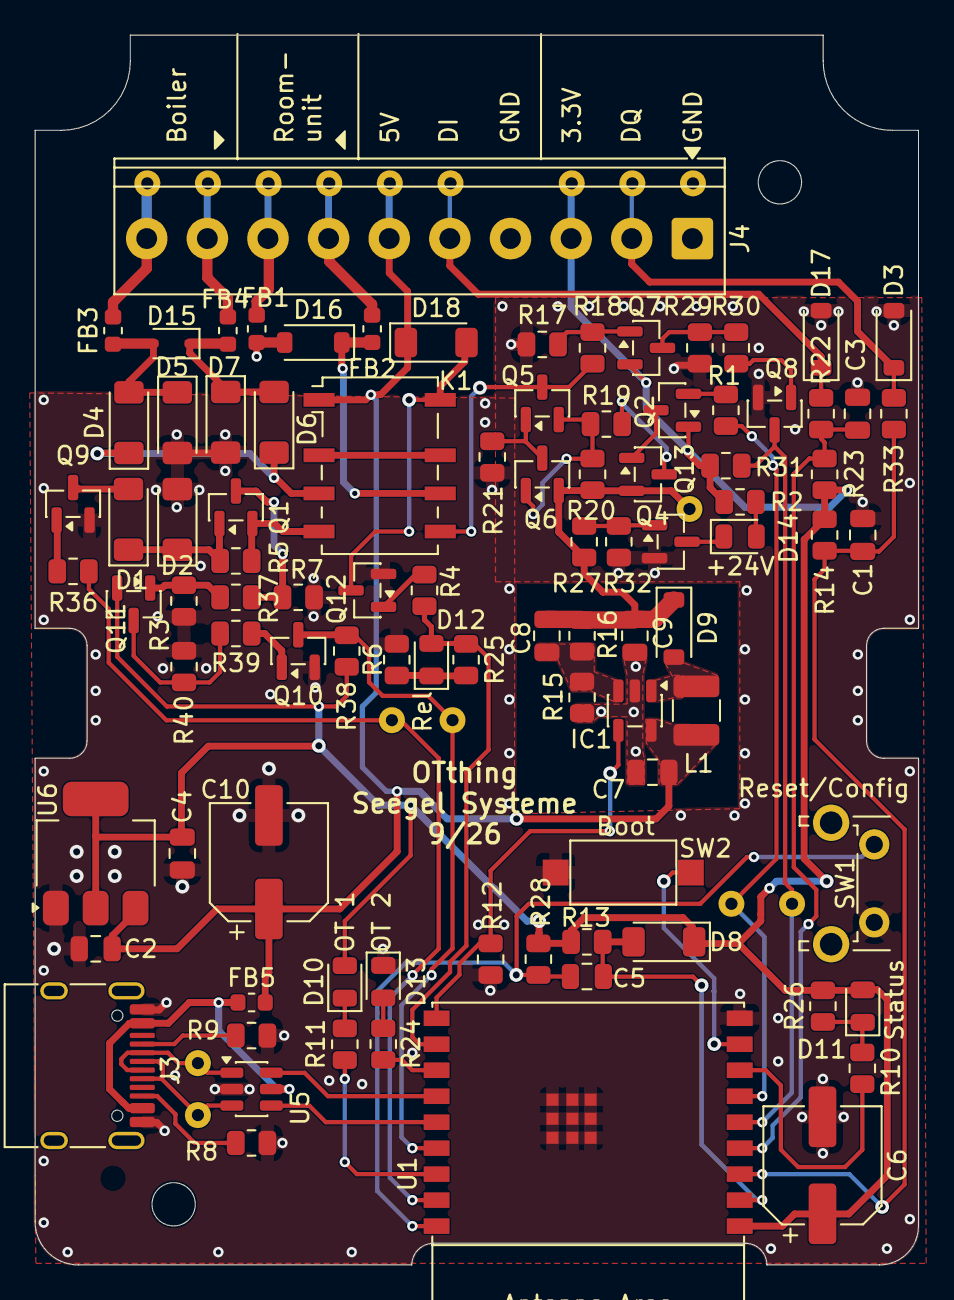
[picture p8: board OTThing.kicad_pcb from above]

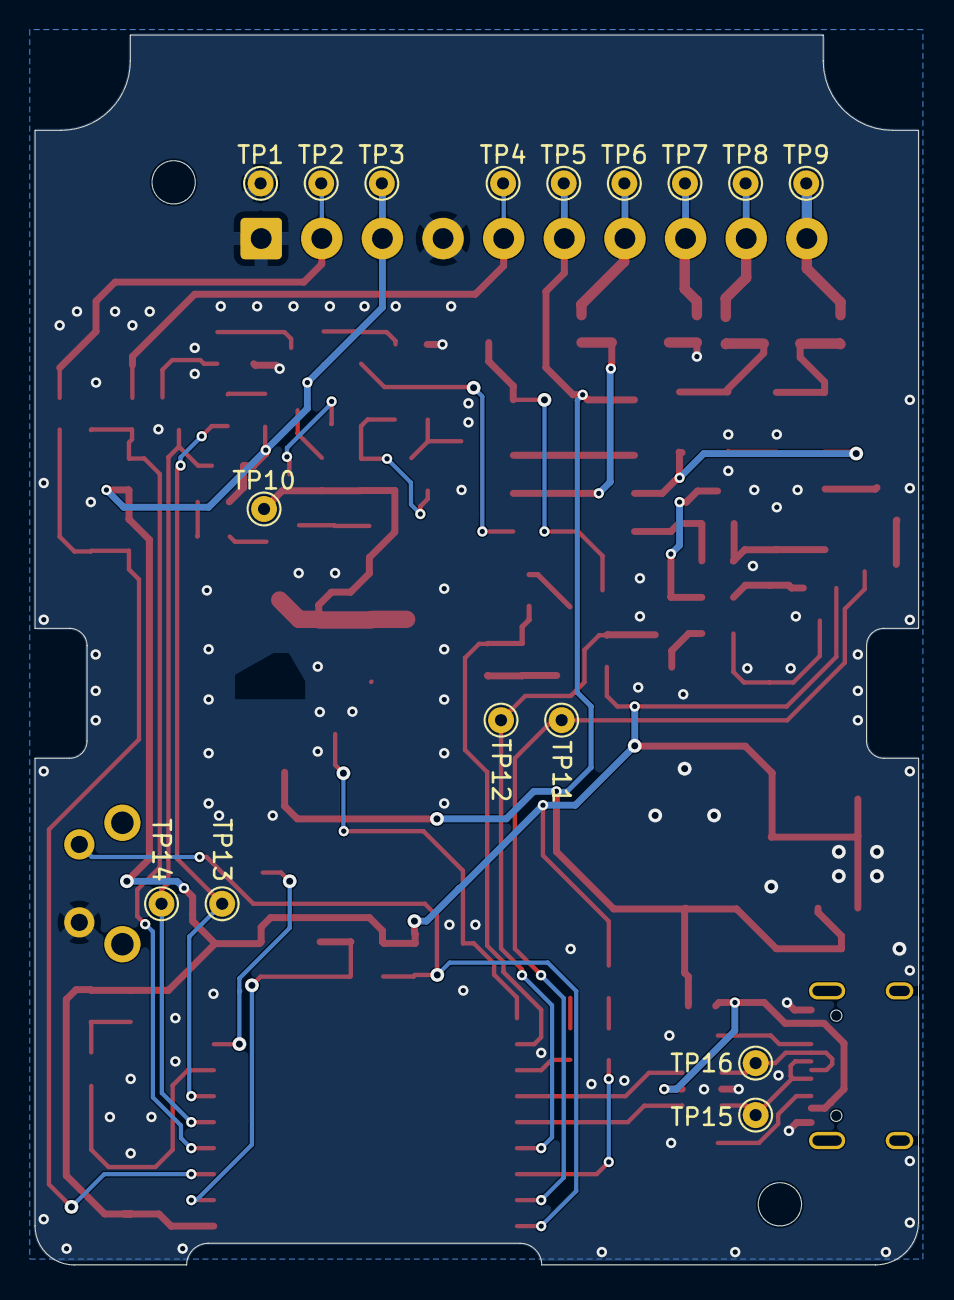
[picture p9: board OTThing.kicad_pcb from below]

Board: 2 copper layers, 51.0 x 71.0 mm, 111 parts (16 on the bottom side), 64 nets.

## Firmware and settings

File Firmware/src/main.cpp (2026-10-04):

#include <Arduino.h>
#include "hwdef.h"
#include "portal.h"
#include "otcontrol.h"
#include "mqtt.h"
#include "devstatus.h"
#include "devconfig.h"
#include "command.h"
#include "sensors.h"
#include "HADiscLocal.h"
#include "time.h"
#include "main.h"
#include "util.h"
#include "esp_task_wdt.h"
#include "auxInput.h"
#include "netw.h"
#include "StatusLed.h"

#ifdef DEBUG
    #include <ArduinoOTA.h>
#endif

bool configMode = false;

#ifdef DEBUG
// Required for DEBUG build: definitions for BLE externs referenced by command.cpp.
NimBLECharacteristic *bleSerialTx = nullptr;
volatile bool bleClientConnected = false;
#endif


void setup() {
    statusLed.begin();
    pinMode(GPIO_CONFIG_BUTTON, INPUT);
    pinMode(GPIO_BOOT_BUTTON, INPUT_PULLUP);
    pinMode(GPIO_BYPASS_RELAY, INPUT_PULLUP);

    Serial.begin();
    Serial.setTxTimeoutMs(100);

    otcontrol.begin();
    devconfig.begin();

    configMode = digitalRead(GPIO_CONFIG_BUTTON) == 0;
    configMode |= !netw.hasStoredWifiCredentials();
    if (configMode)
        statusLed.set(StatusLed::LED_CONFIG);

    netw.begin(configMode);
    
    AddressableSensor::begin();
    BLESensor::begin();
    haDisc.begin();
    mqtt.begin();
    configTime(devconfig.getTimezone(), 3600, PSTR("pool.ntp.org"));

    portal.begin(configMode);

    command.begin();

    esp_task_wdt_add(NULL);

#ifdef DEBUG
    ArduinoOTA.begin();
#endif
}

void loop() {
    unsigned long now = millis();

    static unsigned long btnDown = 0;
    if (digitalRead(GPIO_CONFIG_BUTTON) == 0) {
        if ((now - btnDown) > 10000) {
            statusLed.end();
            setLedStatus(true);
            devconfig.remove();
            netw.end();
            WiFi.persistent(true);
            WiFi.disconnect(true, true);
            esp_wifi_restore();
            while (digitalRead(GPIO_CONFIG_BUTTON) == 0) {
                esp_task_wdt_reset();
                yield();
            }
            ESP.restart();
        }
        esp_task_wdt_reset();
        return;
    }
    else
        btnDown = now;

    static bool oldBootButtonState = false;

    if (oldBootButtonState != (digitalRead(GPIO_BOOT_BUTTON) == 0)) {
        netw.startWps();
        oldBootButtonState = digitalRead(GPIO_BOOT_BUTTON) == 0;
    }

#ifdef DEBUG
    ArduinoOTA.handle();
#endif
    esp_task_wdt_reset();
    portal.loop();
    mqtt.loop();
    otcontrol.loop();
    Sensor::loopAll();
    devconfig.loop();
    OneWireNode::loop();

    if (configMode)
        netw.loop();

    for (int i=0; i<sizeof(auxInput) / sizeof(auxInput[0]); i++)
        auxInput[i].loop();
}

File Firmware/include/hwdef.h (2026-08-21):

#pragma once

#define GPIO_CONFIG_BUTTON 0
#define GPIO_BOOT_BUTTON 9
#define GPIO_STATUS_LED 8
#define GPIO_OTRED_LED 2
#define GPIO_OTGREEN_LED 21
#define GPIO_BYPASS_RELAY 20
#define GPIO_STEPUP_ENABLE 10
#define GPIO_1WIRE_DIO 4
#define GPIO_OTSLAVE_IN 6
#define GPIO_OTSLAVE_OUT 7
#define GPIO_OTMASTER_IN 3
#define GPIO_OTMASTER_OUT 1
#define GPIO_AUX_IN 5

inline void setLedOTRed(const bool on) {
    digitalWrite(GPIO_OTRED_LED, !on);
}

inline void setLedOTGreen(const bool on) {
    digitalWrite(GPIO_OTGREEN_LED, on);
}

inline void setLedStatus(const bool on) {
    digitalWrite(GPIO_STATUS_LED, !on);
}

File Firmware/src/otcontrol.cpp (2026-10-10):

#include <WiFi.h>
#include "otcontrol.h"
#include "auxInput.h"
#include "command.h"
#include "HADiscLocal.h"
#include "mqtt.h"
#include "hwdef.h"
#include "portal.h"
#include "sensors.h"
#include "devstatus.h"

const char SLAVE_BRAND[] PROGMEM = "Seegel Systeme";

using enum OpenThermMessageID;

OTControl otcontrol;

constexpr uint16_t floatToOT(double f) {
    return (((int) f) << 8) | (int) ((f - (int) f) * 256);
}

constexpr uint16_t nib(uint8_t hb, uint8_t lb) {
    return (hb << 8) | lb;
}

class SemMaster {
private:
    BaseType_t result;
public:
    SemMaster(const uint16_t timeout) {
        result = xSemaphoreTakeRecursive(otcontrol.master.mutex, (TickType_t) timeout / portTICK_PERIOD_MS);
        wait();
    }

    ~SemMaster() {
        if (result == true) {
            wait();
            xSemaphoreGiveRecursive(otcontrol.master.mutex);
        }
    }

    operator bool() {
        return (result == pdTRUE) && otcontrol.master.hal.isReady();
    }

    void wait() {
        if (result == pdTRUE) {
            TickType_t start = xTaskGetTickCount();

            while (!otcontrol.master.hal.isReady()) {
                if ((xTaskGetTickCount() - start) > pdMS_TO_TICKS(2000))
                    break;

                otcontrol.hwYield();
            }
        }
    }
};

void IRAM_ATTR handleIrqMaster() {
    otcontrol.masterPinIrq();
}

void IRAM_ATTR handleIrqSlave() {
    otcontrol.slavePinIrq();
}

//OpenTherm master callback
void otCbMaster(unsigned long response, OpenThermResponseStatus status) {
    otcontrol.OnRxMaster(response, status);
}

//OpenTherm slave callback
void otCbSlave(unsigned long response, OpenThermResponseStatus status) {
    otcontrol.OnRxSlave(response, status);
}

OTControl::OTInterface::OTInterface(const uint8_t inPin, const uint8_t outPin, const bool isSlave):
        hal(inPin, outPin, isSlave) {
    resetCounters();
    mutex = xSemaphoreCreateRecursiveMutex();
}

void OTControl::OTInterface::sendRequest(const char source, const unsigned long msg) {
    const bool sent = hal.sendRequestAsync(msg);

    if (sent) {
        if (source)
            command.sendOtEvent(source, msg);
        txCount++;
        lastTx = millis();
    }
}

void OTControl::OTInterface::resetCounters() {
    txCount = 0;
    rxCount = 0;
    timeoutCount = 0;
    invalidCount = 0;
}

void OTControl::OTInterface::onReceive(const char source, const unsigned long msg) {
    if (source)
        command.sendOtEvent(source, msg);
    rxCount++;
    lastRx = millis();
}

void OTControl::OTInterface::sendResponse(const char source, const unsigned long msg) {
    uint32_t temp = millis();

    while (true) {
        if (hal.sendResponse(msg)) {
            if (source)
                command.sendOtEvent(source, msg);
        
            txCount++;
            lastTx = millis();
            break;
        }
        if (millis() - temp > 300)
            break;

        hal.process();
        yield();
    }
}

bool OTControl::OTInterface::isConnected() const {
    return millis() - lastRx < 2000; // consider connected if received a message within the last 2 seconds
}

void OTControl::OTInterface::writeJson(JsonObject &obj) const {
    obj["connected"] = isConnected();
    obj[FPSTR(STR_STATKEY_TXCOUNT)] = txCount;
    obj[FPSTR(STR_STATKEY_RXCOUNT)] = rxCount;
}

OTControl::OTControl():
        lastBoilerStatus(0),
        otMode(OTMODE_MASTER_SLAVE),
        slaveApp(SLAVEAPP_HEATCOOL),
        chcontrol{CHcontrol(0), CHcontrol(1)},
        setBoilerRequest{OTWRSetBoilerTemp(0), OTWRSetBoilerTemp(1)},
        setRoomTemp{OTWRSetRoomTemp(0), OTWRSetRoomTemp(1)},
        setRoomSetPoint{OTWRSetRoomSetPoint(0), OTWRSetRoomSetPoint(1)},
        master(GPIO_OTMASTER_IN, GPIO_OTMASTER_OUT, false),
        slave(GPIO_OTSLAVE_IN, GPIO_OTSLAVE_OUT, true) {
}

void OTControl::begin() {
    pinMode(GPIO_OTRED_LED, OUTPUT);
    pinMode(GPIO_OTGREEN_LED, OUTPUT);
    pinMode(GPIO_STEPUP_ENABLE, OUTPUT); // +24V enable for room unit (OT slave)
    pinMode(GPIO_BYPASS_RELAY, OUTPUT); // relay
    
    setLedOTGreen(false);
    setLedOTRed(false);

    master.hal.begin(handleIrqMaster, otCbMaster);
    slave.hal.begin(handleIrqSlave, otCbSlave);

    setOTMode(OTMODE_MASTER_SLAVE);
}

void OTControl::masterPinIrq() {
    bool state = digitalRead(GPIO_OTMASTER_IN);

    if (otMode == OTMODE_MASTER) // in master mode green LED is used for RX, red LED for TX
        setLedOTGreen(state);
    else
        setLedOTRed(state);
    
    master.hal.handleInterrupt();
}

void OTControl::slavePinIrq() {
    const bool state = digitalRead(GPIO_OTSLAVE_IN);
    setLedOTGreen(state);
    slave.hal.handleInterrupt();
}

uint16_t OTControl::tmpToData(const double tmpf) {
    if (tmpf > 100)
        return 100<<8;
    if (tmpf < -100)
        return - (int) (100<<8);
    
    return (int16_t) (tmpf * 256);
}

void OTControl::setOTMode(const OTMode mode) {
    otMode = mode;

    // set bypass relay
    digitalWrite(GPIO_BYPASS_RELAY, !bypass);

    // set +24V stepup up
    bool slaveEn = (mode == OTMODE_MASTER_SLAVE) || (mode == OTMODE_REPEATER);
    digitalWrite(GPIO_STEPUP_ENABLE, slaveEn && !bypass);

    for (auto *valobj: slaveValues)
        valobj->init(isMaster());

    for (auto *valobj: masterValues)
        valobj->init(false);

    for (auto *valobj: roomUnitValues)
        valobj->init(false);

    master.hal.setAlwaysReceive(mode == OTMODE_REPEATER);

    SemMaster sem(100);
    delay(200); // give some time for master to switch to new mode
    master.hal.requestLowPower();
}

bool OTControl::getOverrideEnabled() const {
    return (otMode == OTMODE_MASTER_SLAVE) || (otMode == OTMODE_REPEATER);
}

void OTControl::setBypass(const bool bypass) {
    if (this->bypass != bypass) {
        this->bypass = bypass;
        setOTMode(otMode);
    }    
}

void OTControl::setSummerMode(const bool summerMode) {
    boilerCtrl.summerMode = summerMode;
}

void OTControl::setDhwBlocking(const bool dhwBlocking) {
    boilerCtrl.dhwBlocking = dhwBlocking;
}

bool OTControl::getFlame() const {
    return OTValue::status->getFlame();
}

// return weather a slave (e. g. boiler) is connected to OTthing's master interface
bool OTControl::masterConnected() const {
    return master.isConnected();
}

// return weather a master (e. g. roomunit) is connected to OTthing's slave interface
bool OTControl::slaveConnected() const {
    return slave.isConnected();
}

void OTControl::hwYield() {
    vTaskDelay(1);
    master.hal.process();
    slave.hal.process();
    
    if (otMode == OTMODE_MASTER) {
        // in OTMASTER mode use OT LEDs as master TX & RX
        if (millis() > master.lastTx + 50)
            setLedOTRed(false);
    }
}
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

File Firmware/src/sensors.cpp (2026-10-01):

#include "sensors.h"
#include <DallasTemperature.h>
#include "HADiscLocal.h"
#include "devstatus.h"

Sensor roomTemp[2] = {
    Sensor(0.2),
    Sensor(0.2)
};
AutoSensor roomSetPoint[2];
OutsideTemp outsideTemp;
Sensor returnTemp[2] = {
    Sensor(0.4),
    Sensor(0.4)
};

SemaphoreHandle_t AddressableSensor::mutex;
Sensor* Sensor::lastSensor = nullptr;
uint32_t Sensor::lastSmooth = 0;
BLESensor* BLESensor::last = nullptr;
OneWireNode *OneWireNode::last = nullptr;
static OneWire oneWire;

class SensorLock: public SemHelper {
public:
    SensorLock(): SemHelper(AddressableSensor::mutex, 100) {    
    }
};

Sensor::Sensor(const double alpha):
    src(SOURCE_NA),
    setFlag(false),
    alpha(alpha) {
    prevSensor = lastSensor;
    lastSensor = this;
}

void Sensor::set(const double val, const Source src, const Source lastSrc) {
    if ((src == this->src) || (src == SOURCE_NA)) {
        value = val;
        if ((!setFlag) || (alpha == 1.0))
            smoothed = val;
        setFlag = true;
        lastSetSrc = src;
        if (lastSrc != SOURCE_NA)
            lastSetSrc = lastSrc;
        else if (lastSrc != SOURCE_NA)
            lastSetSrc = lastSrc;
    }
}

void Sensor::updateSmooth() {
    smoothed = alpha * value + (1.0 - alpha) * smoothed;
}

bool Sensor::get(double &val, const bool raw) {
    if (src == SOURCE_BLE) {
        SensorLock lock;
        if (!lock)
            return false;

        auto *sensor = BLESensor::find(adr);
        if (sensor != nullptr)
            set(sensor->temp, SOURCE_BLE);
    }

    if (setFlag) {
        if (raw)
            val = value;
        else
            val = smoothed;
        val = round(val * 10) / 10;
    }
    
    return setFlag;
}

void Sensor::writeJson(JsonVariant val) {
    double d;
    if (!get(d))
        val.set(nullptr);
    else {
        JsonObject obj = val.to<JsonObject>();
        obj[F("current")] = round(smoothed * 10) / 10;
        obj[F("raw")] = round(value * 10) / 10;
        obj[STR_STATKEY_LASTSETPOINTSRC] = lastSetSrc;
    }
}

Sensor::operator bool() const {
    return setFlag;
}

std::vector<Sensor*> Sensor::findByOwn(const OneWireNode *own) {
    std::vector<Sensor*> result;
    Sensor *item = lastSensor;
    while (item) {
        if (item->own == own)
            result.push_back(item);
        item = item->prevSensor;
    }
    return result;
}

void Sensor::setConfig(JsonObject &obj) {
    auto newSrc = (Source) (obj["source"] | (int) SOURCE_NA);
    if (src != newSrc) {
        setFlag = false;
        src = newSrc;
    }
    
    own = nullptr;
    switch (src) {
    case SOURCE_1WIRE:
        own = OneWireNode::find(String(obj["adr"]));
        setFlag = false;
        break;

    case SOURCE_BLE:
        for (int i=0; i<6; i++)
            adr[i] = strtol(String(obj[F("adr")]).substring(i * 2, i * 2 + 2).c_str(), 0, 16);
        break;

    default:
        break;
    }
}

bool Sensor::isMqttSource() {
    return (src == SOURCE_MQTT) || (src == SOURCE_AUTO);
}

bool Sensor::isOtSource() {
    return (src == SOURCE_OT);
}

void Sensor::loopAll() {
    const bool smooth = ((millis() - lastSmooth) >= 60000);
    if (smooth)
        lastSmooth = millis();
    
    Sensor *item = lastSensor;
    while (item) {
        item->loop();
        if (smooth && item->setFlag)
            item->updateSmooth();
        item = item->prevSensor;
    }
}

AutoSensor::AutoSensor():
    Sensor(1.0) {
    memset(values, 0, sizeof(values));
}

void AutoSensor::set(const double val, const Source src, const Source lastSrc) {
    if ((this->src == SOURCE_AUTO) && (src != SOURCE_NA)) {
        if (val != values[src]) {
            Sensor::set(val, SOURCE_AUTO, lastSrc);
            values[src] = val;
        }
    }
    else
        Sensor::set(val, src, lastSrc);
}

OutsideTemp::OutsideTemp():
        Sensor(0.2),
        nextMillis(0),
        httpState(HTTP_IDLE) {

    acli.onData([this](void *arg, AsyncClient *client, void *data, size_t len) {
        replyBuf += String((char*) data, len);
    });

    acli.onDisconnect([](void *arg, AsyncClient *client) {
        client->close();
    });

    acli.onError([](void *arg, AsyncClient *client, int8_t error) {
        client->close();
    });
}

void OutsideTemp::setConfig(JsonObject &obj) {
    Sensor::setConfig(obj);
    lat = obj[F("lat")];
    lon = obj[F("lon")];
    apikey = obj[F("apikey")].as<String>();
    interval = (uint16_t) obj[F("interval")] * 1000;
    if (interval == 0)
        interval = 30000;
    owResult.clear();
    nextMillis = 0;
}

void OutsideTemp::set(const double val, const Source src, const Source lastSrc) {
    Sensor::set(val, src, lastSrc);

    struct tm timeinfo;
    if (!getLocalTime(&timeinfo, 0))
        return;

    const int currentHour = timeinfo.tm_hour;
    if (lastHistPos < 0) {
        // first call ever: seed all hourly slots so avg is not skewed by zeros
        for (int i=0; i<sizeof(minValues)/sizeof(minValues[0]); i++)
            minValues[i] = maxValues[i] = val;
    }
    else if (currentHour != lastHistPos)
        minValues[currentHour] = maxValues[currentHour] = val;

    lastHistPos = currentHour;
    if (val < minValues[currentHour])
        minValues[currentHour] = val;
    if (val > maxValues[currentHour])
        maxValues[currentHour] = val;
}

void OutsideTemp::writeJson(JsonVariant val) {
    Sensor::writeJson(val);
    if (!setFlag)
        return;

    JsonObject obj = val.as<JsonObject>();
    double minVal = value, maxVal = value;
    for (int i=0; i<sizeof(minValues)/sizeof(minValues[0]); i++) {
        if (minValues[i] < minVal)
            minVal = minValues[i];
        if (maxValues[i] > maxVal)
            maxVal = maxValues[i];
    }
    obj[F("min")] = minVal;
    obj[F("max")] = maxVal;
    obj[F("avg")] = getAvg();
}

double OutsideTemp::getAvg() const {
    double avgVal = 0;
    for (int i=0; i<sizeof(minValues)/sizeof(minValues[0]); i++) {
        avgVal += (minValues[i] + maxValues[i]) / 2.0;
    }
    return avgVal / (sizeof(minValues)/sizeof(minValues[0]));
}
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

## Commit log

2024-09-02 init commit
    [OTThing.csv, OTThing.kicad_pcb, OTThing.kicad_sch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]
2024-09-09 change MCU redesign OT interfaces
    [OTThing.kicad_pcb, OTThing.kicad_sch, otinterface.kicad_sch]
2024-10-14 Change MCU
    [OTThing.csv, OTThing.kicad_pcb, OTThing.kicad_sch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]
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2024-11-05 finish 45/24
    [OTThing.kicad_pcb, OTThing.kicad_sch, otinterface.kicad_sch]
2025-01-08 add pullups for stability
    [OTThing.kicad_pcb, OTThing.kicad_sch, otinterface.kicad_sch]
2025-01-08 Home Assistant Discovery
    OpenTherm timer TX
    WiFi client for openweather
    OT loopback test
2025-01-09 add factory reset
    select OT mode from webUI
    OT loopback tests
    [hwdef.h, main.cpp, otcontrol.cpp]
2025-01-13 add HA climate for dhw
    calc flowtemp from outsidetemp
2025-01-13 add LED for +24V enable
    [OTThing.kicad_pcb, OTThing.kicad_sch]
2025-01-16 webUI log output fix MQTT credentials set DHW temp & CH temp via MQTT
    [hwdef.h, main.cpp, otcontrol.cpp]
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2025-02-01 boiler's sensor for outside temperature fix TX counter
    [otcontrol.cpp]
2025-03-27 migrate to pioarduino smart power add more OT values new partitiontable
    [OTThing.kicad_pcb, OTThing.kicad_sch, otinterface.kicad_sch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]
2025-03-28 Migrate to KiCad 9.0
    [OTThing.kicad_pcb, otinterface.kicad_sch]
2025-03-28 add Test PCB
    [OT Thing Tester.kicad_pcb, OT Thing Tester.kicad_sch]
2025-03-29 increase app partition size autoscroll button add OT val room override
    [partitions.csv]
2025-03-30 fix update progress bar remove repeater mode remove debug outputs
    [otcontrol.cpp]
2025-03-31 rename gateway -> repeater fix delay
    [otcontrol.cpp]
2025-07-18 fix mqtt payload string fix OT repeater, forwarding unknown frames add interpreter for OT value remote specific flags
    [main.cpp, otcontrol.cpp]
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2025-09-25 refresh heat curve when changing default room set point for flow temp when chaning room set point show smartpowerenabled flag
2025-09-25 add USB test points single board test w/ power supply
    [OT Thing Tester.kicad_pcb, OT Thing Tester.kicad_sch, OTThing.kicad_pcb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]
2025-10-23 add 3d model
    [OT Thing Tester.kicad_pcb]
2025-11-01 release fix slaveEnable in mastermode
    [otcontrol.cpp]
2025-11-18 add status USB CDC connect to webUI add OT field OEM diagnostic code fix mqtt disconnection counter add HA discovery flags for master status add HA discovery flags for slave status add HA discovery f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
    [otcontrol.cpp]
2025-11-18 fix override in master mode with slave add mod & override to status
    [otcontrol.cpp]
2025-11-19 Add HA discovery for max. capacity & min. modulation Add HA discovery for DHW bounds Add HA discovery for CH bounds
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2025-11-22 send outside temp to boiler fix outside temp < 0
    [otcontrol.cpp]
2025-11-28 new production
    [OTThing.kicad_pcb, otinterface.kicad_sch]
2025-12-07 add OT value boiler heat exchanger temp add OT value boiler fan speed add OT value flame current fix ventilation fan speed refactoring
    [otcontrol.cpp]
2025-12-10 change TVS diodes
    [OTThing.kicad_pcb, OTThing.kicad_sch, otinterface.kicad_sch]
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2025-12-14 add timezone setting send datetime to roomunit fix sensor paths add image in README
    [main.cpp, otcontrol.cpp]
2026-01-04 Support for BTHome BLE sensors disable CH2 / DHW controls if not supported from boiler
2026-01-05 add switches for enabling room compensation add controls for setting max. modulation
2026-01-08 calculate burner flame ratio & toggle frequency add OT fields CH pump operating hours & DHW pump operating hours save space on heating curve canvas show arrow in heating curve canvas for current flow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
    [main.cpp, otcontrol.cpp]
2026-01-11 add slave (service) requests show reset reason in webUI add watchdog
    [main.cpp, otcontrol.cpp]
2026-01-15 static JSON buffer for status semaphore for device status fix suspend
    [otcontrol.cpp]
2026-01-20 Set PI controller with room climate control add HA sensor for room setpoint fix synchronization
    [main.cpp, otcontrol.cpp]
2026-01-20 read brand, brand version & brand serial from slave fix warnings
    [otcontrol.cpp]
2026-01-22 fix HA warnings fix GCC warnings refactoring discoveries fix deviceclass "opening"
    [otcontrol.cpp]
2026-01-22 remove orphan HA values fix update from github
    [main.cpp, otcontrol.cpp]
2026-01-23 add OT values DHW burner starts & DHW pump starts fix typo remove override controls if caps not present
    [otcontrol.cpp]
2026-01-24 calculate burner flame ratio & toggle frequency add OT fields CH pump operating hours & DHW pump operating hours save space on heating curve canvas show arrow in heating curve canvas for current flow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
    [otcontrol.cpp]
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2026-01-25 add sensor for current room temperature fix hiding CH2 controls
    [otcontrol.cpp]
2026-01-25 fix flag "smart power implemented"
2026-01-25 read size of fault history buffer (FHB) read size of slave transparent parameters (TSPs) read power cycles
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2026-02-05 HA: add device class and unit to number entities
2026-02-09 Fix ERCs, DRCs & BOM
    [OTThing.kicad_pcb, OTThing.kicad_sch, otinterface.kicad_sch]
2026-02-11 fix unit for boiler fan speed sensor
    [otcontrol.cpp]
2026-02-21 update flow imediately when changing room compensation via MQtt
2026-02-22 update libraries, fix DRCs
    [OTThing.kicad_pcb, OTThing.kicad_sch, otinterface.kicad_sch]
2026-03-04 sensors for flame / pausetime per cycle aux input sensor
    [OTThing.kicad_pcb, OTThing.kicad_sch, otinterface.kicad_sch]
2026-03-10 add parameter for min. flow temperatur configurable inputs (1wire, digital, analog) show boost in heatingcurve fix suspend on roomsetpoint in override HTTP endpoint /set OT bypass via MQTT
    [auxInput.cpp, hwdef.h, main.cpp]
2026-03-10 fix ERCs & DRCs add TVS diodes to DQ & DI
    [OTThing.kicad_pcb, OTThing.kicad_sch]
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2026-03-12 fix flame ratio sensor
    [otcontrol.cpp]
2026-03-12 add fiducals
    [OTThing.kicad_pcb, OTThing.kicad_sch, otinterface.kicad_sch]
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2026-03-25 add flow return limit add config backup & restore HA secure value templates HA add mode state to climate controls HA add state to switch controls
2026-03-27 fix select source fields add label when dragging curve move neighbor points when dragging curve fix override logic refactoring
    [otcontrol.cpp]
2026-03-30 build html.h before every build refactoring change multipoint clipping webUI export control CH override seperately for on and flow move flamestats to dedicated class
2026-03-30 add markings for loopback test
    [OTThing.kicad_pcb]
2026-03-30 fix roomcomp ctrl mode
    [otcontrol.cpp]
2026-04-04 fix room compensation clean up
    [otcontrol.cpp]
2026-04-05 fix otMode setting fix input text settings
    [otcontrol.cpp]
2026-04-06 fix update buttons move wificlient
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2026-04-12 fix default mode move production to own python file
    [otcontrol.cpp, production.py]
2026-04-14 fix loopback mode on unprogrammed devices enhanced production script
    [otcontrol.cpp, production.py]
2026-04-18 set style of flow temp marker according to flame state
2026-04-23 show actons in hero cards add contrls to flow set card show current on time when flame on add more mparameters to mock
2026-04-27 fix current on time
2026-05-02 fix: clip negative TSet values from slave instead of ignoring them
    [otcontrol.cpp]
2026-05-02 fix: correct f8.8 negative temperature decoding; configurable exhaust type
    [otcontrol.cpp]
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2026-05-03 fix frame counter
2026-05-05 fix outsideTemp > roomset in heating curve
2026-05-05 fix sensorstatus for smoothed sensors
    [sensors.cpp]
2026-05-07 fix cloaking with many slave values
    [otcontrol.cpp]
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2026-05-12 show warning icon for master values which were not accepted by slave relay value return_r if wired to a (1w) sensor.
2026-05-13 fix result of master status refactor value template for OT fields fix non OT values in master section persistant history data in hero cards
    [otcontrol.cpp]
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2026-05-26 do not advertise smart power to slave force all requests on config change fix large MQTT payload
    [otcontrol.cpp]
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2026-06-01 refactor(auxinput): replace CH-demand mode with digital role on binary mode
    Per upstream review: instead of a dedicated MODE_CH_DEMAND = 5, use an
    additional digitalRole option (none/demand/enable CH1/CH2) on the existing
    MODE_BINARY digital input.
    - AuxInput gains DigitalRole enum; digitalRole persisted in config
    - demand role: contact state OR-ed into CH enable (forces CH on)
    - enable role: contact state AND-ed with CH enable (gates CH)
    - CHcontrol gains auxDemandOn / auxEnableActive / auxEnableOn fields;
    getChOn() applies OR/AND after the existing calcChOn() base result
    - OTControl gains setAuxDemand / setAuxEnable (gated on OTMODE_MASTER);
    aux flags reset in setOTMode() when leaving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
    [auxInput.cpp, otcontrol.cpp]
2026-06-02 HA versions -> diagnostic Fix CH 2 init
    [otcontrol.cpp]
2026-06-02 Migrate to KiCad 10
    [OTThing.kicad_pcb, OTThing.kicad_sch, otinterface.kicad_sch]
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2026-06-20 update KiCad libraries
    [OTThing.kicad_pcb, OTThing.kicad_sch]
2026-06-27 add JSON viewer to mock add missing fields to webUI
    [mock_otthing.py]
2026-07-03 fix flow result fix typo in default config
    [production.py]
2026-07-03 add cooling controls to mock fix pinned boxes outline fix cooling pathes
    [mock_otthing.py]
2026-07-05 add dedicated flow set path add configurable CH of temp add improv WiFi BLE add 2nd flow set control
2026-07-05 fix trend graph with missing values
    [mock_otthing.py]
2026-08-15 add modal WiFi scan dialog fix flow setpoint path WPS support
    [main.cpp, mock_otthing.py]
2026-08-18 DHW setpoint readback fix status lamps logic refactoring fix devname in HA discovery
    [loganalyzer.py, otcontrol.cpp]
2026-08-18 Add herocard for cooling fix vent API
    [loganalyzer.py, otcontrol.cpp]
2026-08-21 enhance WiFi setup dialog add roomunit sensors in master mode add WPS button Status LED class
2026-08-23 fix HA room temp sensor path add sensors for room unit
2026-09-23 add suspend state to herocard lamp add roomunit values to status tab show outsidetemp min/max in heating curve
2026-09-27 add confugurable suspend on outsidetemp add configurable hysteresis to susp. on min. flow add 24h outsidetemp markers
2026-09-27 Tester PCB layout updates
    [OT Thing Tester.kicad_pcb, OT Thing Tester.kicad_sch, OTThing.kicad_pcb]
2026-10-01 rearange roomunit values improve setup layout fix AUX setup more string constants save last source for dhw-setpoint, sensors, flow setpoint fix online status
2026-10-01 fix sensor assignment improv PI on/off switching
    [otcontrol.cpp, sensors.cpp]
2026-10-03 minor design fixes refactoring select elements adding infoboxes add suspension card fix outsidetemp suspension
    [mock_otthing.py]
2026-10-03 fix heatingcurve indicator & redraw
2026-10-04 fix setting OT mode
    [loganalyzer.py, main.cpp, otcontrol.cpp]
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2026-10-04 fix reload state for "pin" and "scroll" option
2026-10-10 add /curve1 & /curve2 for viewing heating curve only add hero card lamps for master / slave connection add min/max flow to heating curve diagram refactor mode / bypass configuration refactor HA disco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
2026-10-15 fix MQTT que
2026-10-15 add card with average outside temp in webUI testing rounded flow settemp
2026-10-16 show legend for heating curve refactor strings increase threshold for OT timeout detection
2026-10-21 BLE sensor: ignore invalid/stale temperature, add timeout
    - initialize BLESensor temp/rh/bat/rssi, track validity and time of last temperature
    - Sensor::get() reports BLE source unavailable when no valid value or older than 30 min
    (avoids smoothing seeded with 0 after boot and frozen values when the sensor stops advertising)
    - parse(): explicit uint8_t casts, int16 decoding, length checks, plausibility range
    - status JSON: temp/rh/bat null when not (yet) received, new field 'age'
    - HA discovery: diagnostic entity for the temperature age
    - dashboard: render --- instead of null for temp/rh/bat
2026-10-23 fix: min. flow suspension released early by room compensation loop
    loopRoomComp() reset roomComp.deltaT to 0 before calling getChOn(). getChOn()
    calls getFlow(), which adds roomComp.deltaT and, as a side effect, updates the
    min. flow suspension state (minSuspended). Every 30 s the suspension was
    therefore re-evaluated against the bare heating curve without room
    compensation.
    When the bare curve is above flowMin + minSuspendHyst but the compensated flow
    is below it (typical during a night setback: room above setpoint, negative
    roomComp), this cleared minSuspended. The next regular getFlow() call with the
    real deltaT only sets it again below flowMin - minSuspendHyst, so inside the
    hysteresis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
2026-10-31 fix HA templates add HA sensors current off time, last off time select option for using CH off temp
2026-11-01 fix entity IDs fix reset_reason status add HA sensor for reset_reason
2026-11-05 faster requests for fast changing sensors add production as target fix units for turbo mode update README
2026-11-06 roomComp: make integration factor for too warm room configurable
    The integrator decreases with 0.3 * Ki when the room is warmer than
    the setpoint. Together with the deadband this asymmetry lets the
    integrator creep up with a daily night setback until it sticks at the
    anti-windup limit.
    New option heating[].roomComp.coolFactor (default 0.3, range 0.1..1).
    The default keeps the current behaviour.
2026-11-08 Improve Wi-Fi/BLE coexistence and defer BLE scan until Wi-Fi is settled
    - Enable WIFI_PS_MIN_MODEM instead of WIFI_PS_NONE in OtNetwork::begin() as required for ESP32-C3 single-antenna Wi-Fi/BLE coexistence.
    - Pause BLE scanning while Wi-Fi STA is disconnected and wait 10 seconds after Wi-Fi connects before starting the continuous BLE scan so association, DHCP, mDNS, and initial MQTT discovery complete w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
2026-11-13 fix sampling of pinned cards fix availability of slave onnected sensor change WiFi connection strategy add function for read HW version fix hostname
